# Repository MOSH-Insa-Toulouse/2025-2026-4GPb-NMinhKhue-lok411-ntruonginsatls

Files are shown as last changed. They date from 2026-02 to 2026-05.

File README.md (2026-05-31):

# Projet: Capteur Graphite à Crayon
MOSH projet crée par les étudiant.es en 4ème année de Génie Physique: 
**NGUYEN Minh Khue, VO Phuc Loc, TRUONG Nguyen Gia Khanh**

# Tableau de matière
- [Introduction](#introduction)
  - [Objectifs](#1-objectifs)
  - [Conception](#2-conception)
  - [Matériels nécessaires](#3-matériels-nécessaires)
  - [Livrables](#4-livrables)
- [Réalisation du projet](#réalisation-du-projet)
  - [Schémas](#1-schémas)
    - [Wiring diagram et Simulation LTspice](#11-wiring-diagram-et-simulation-ltspice)
    - [Connection diagram et KiCad](#12-connection-diagram-et-kicad)
  - [Software](#2-software)
    - [Code Arduino](#21-code-arduino)
    - [Application Android sur MIT App Inventor](#22-application-android-sur-mit-app-inventor)
  - [Banc de test](#3-banc-de-test)
    - [Principe](#31-principe)
    - [Résultats](#32-résultats)
- [Conclusion](#conclusion)
- [Contacts](#contacts)
## Introduction

### 1. Objectifs
Le projet est dans le cadre de l’UF « Du capteur au banc de test en open source hardware » en 4ᵉ année de Génie Physique à l’INSA Toulouse. Il est inspiré du rapport scientifique "Pencil Drawn Strain Gauges and Chemiresistors on Paper", publié en 2014 par Cheng-Wei Lin*, Zhibo Zhao*, Jaemyung Kim & Jiaxing Huang dans lequel les auteurs ont proposé un nouveau type de jauge de contrainte basé sur graphite. Le principe repose sur le fait que la résistance électrique du graphite varie lorsque le papier est déformé. En effet, la déformation modifie la distance entre les grains de graphite, ce qui entraîne une variation de la conductance du capteur. En mesurant cette variation de résistance, il est possible d’estimer la contrainte appliquée.

Le premier objectif est donc de concevoir un système qui nous permet de faire un banc de test en mesurant les capteurs simples à graphite pour les comparer avec les capteurs commerciales. De plus, le système doit être contrôlable. Le deuximème objectif est d'évaluer l'industriabilité de ce nouveau type de capteur à partir des mesures.

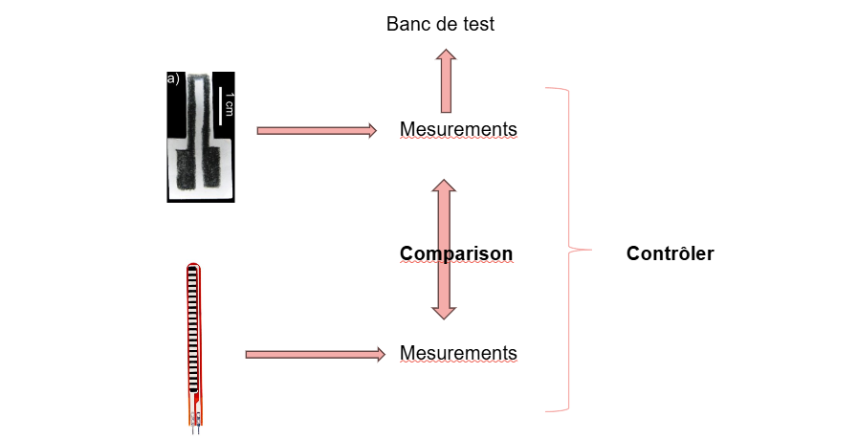
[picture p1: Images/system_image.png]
Système
 

### 2. Conception
Pour regrouper plusieurs fonctions, cela vaut mieux que nous réalisons un shield Arduino. Nous pouvons contrôler les mesures soit manuellement avec un encoder rotatif via un écran OLED, soit à distance via un module Bluetooth et une application Android. Toutes ces idées sont synthétisé dans la figure ci-dessous.

Les détails sont décrits dans la partie de la réalisation.

(apres) nous avons manuellement soudé l'ensemble des modules arduino et composants électroniques (résistances, capacités, amplificateur opérationnel) au PCB imprimé.

(apres) Le Shield réalisé intègre un amplificateur de signal LTC1050 pour amplifier les faibles signaux des capteurs avec précision, un encodeur rotatif permettant de naviguer dans le menu et de modifier les valeurs de résistance via un potentiomètre, un écran OLED pour afficher clairement les menus et les informations, ainsi qu’un module Bluetooth assurant la communication sans fil avec un téléphone portable pour le contrôle et la supervision à distance du système.

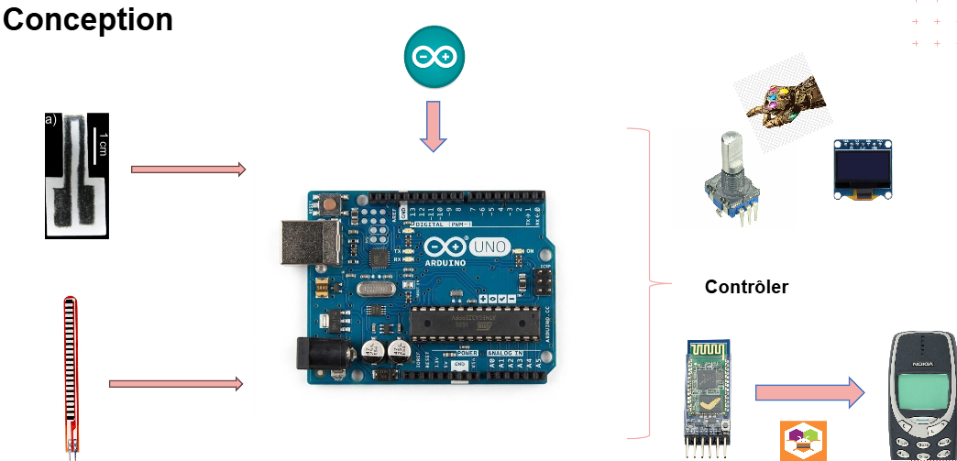
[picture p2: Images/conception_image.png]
Shield


### 3. Matériels nécessaires 
Avec la conception, nous avons décidé que ces composants listés ci-dessous sont suffisants, tout est disponible dans la salle d'instrumentation :
- 1 Carte Arduino UNO
- 1 Module Bluetooth (HC-05)
- 1 Encoder rotatif (Keyes KY-040)
- 1 Écran OLED
- 1 Capteur en graphite fait à l'aide de la couche d'un crayon de papier
- 1 Capteur de flexion commercial (LLC 1070)
- 1 Potentiomètre numérique (MCP41100)
- 1 Amplificateur de transimpédance (LTC1050)
- 2 Supports IC 
- 1 Résistance 1kΩ, 2 résistances 10kΩ, 2 résistances 100kΩ
- 3 condensateurs 100nF, 1 condensateur 1µF

### 4. Livrables
Plusieurs livrables sont contenus dans notre repositoire :
- **Un shield PCB connecté à une carte Arduino UNO** avec differents composants.
- Fiches techniques des composants (HC-05, Keyes KY-040, SSD 1306, LLC 1070, LTC1050, MCP41100)
- **Un code Arduino** qui gère les différents composants cités précédemments (mesures de résistance d'une jauge de contrainte faite en graphite, la communication avec un module Bluetooth, l'affichage sur l'écran OLED d'actions possibles et la gestion du potentiomètre digital permettant la calibration de notre capteur).
- **Une application Android** (grâce aux Tutoriels MIT App Inventor) permet de connecter le PCB et le code Arduino.
- La datasheet du capteur de contrainte en graphite.
- Les fichiers de simulation LTSpice et KiCad.

## Réalisation du projet

### 1. Schémas
La réalisation doit tout d'abord commencer par des schémas électriques tels que le Wiring diagram et le Connection diagram.

#### 1.1. Wiring diagram et Simulation LTspice
Ce diagramme a pour but de savoir comment on peut connecter le capteur à l'Arduino afin que les signaux des mesures soient captées par l'Arduino.

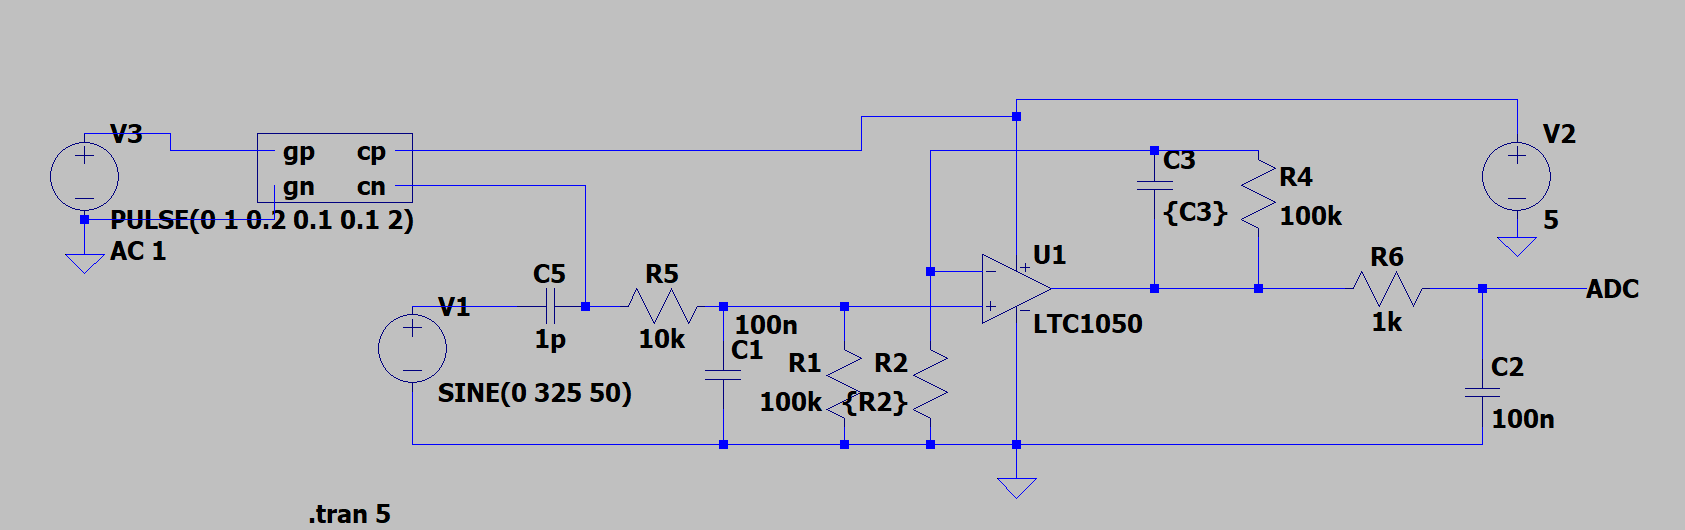
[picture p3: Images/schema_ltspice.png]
Schéma du montage sur LtSpice


Nous souhaitons mesurer la résistance de notre capteur en graphite. Lorsque la résistance interne de notre capteur de graphite est de l'ordre du GΩ. Le courant généré lorsque nous appliquons une tension de 5V est très faible. Pour pouvoir utiliser ce signal, nous le faisons passer par un amplificateur transimpédance (ici nous choisissons LTC 1050) car il possède une capacité à accepter en entrée un courant très faible et un offset de tension bas. Ce montage est constitué d'un amplificateur opérationnel (AO) pour fournir un signal suffisamment large au convertisseur analogique-numérique (ADC) de l'Arduino UNO.

En plus de l'AOP, nous ajoutons 3 filtres:
- À l'entrée, un filtre passe bas passif composé de R1 et C1 de fréquence de coupure de 16Hz pour filtrer les bruits en courant sur le signal d'entrée.
- Une filtre passe bas actif composé de R3 et C4 de fréquence de coupure de 1.6Hz permettane de filtre la composante de bruit à 50Hz provenant du couplage avec le réseau éléctrique.
- En sortie, un dernier filtre composé de R6 et C2 de fréquence de 1.6kHz qui permet de retirer le bruit créé pendant le traitement i.e. bruits des alimentations, de l'horloge, etc.

La résistance R5 est placé en amont de l'AO pour le protéger contre des décharges électrostatiques. Pour notre simulation, nous avons placé la capacité C3 de sorte à ce qu'elle filtre le bruit de l'alimentation. Ainsi, la résistance R2 sera remplacé par une résistance variable (un potentiomètre digital) qui va nous permettre de régler le gain de notre AO en fonction de notre besoin.

Une fois dessiné le Wiring diagram, nous avons vérifié ses comportements et les valeurs de ses composants électriques (résistances, condensateurs,e tc.) grâce aux simulations du logiciel LTspice. (voir l'onglet caché ci-dessous)
<details>
<summary><strong>Simulation LTspice</strong></summary>

- **Fonctionnalité de condition nominale**

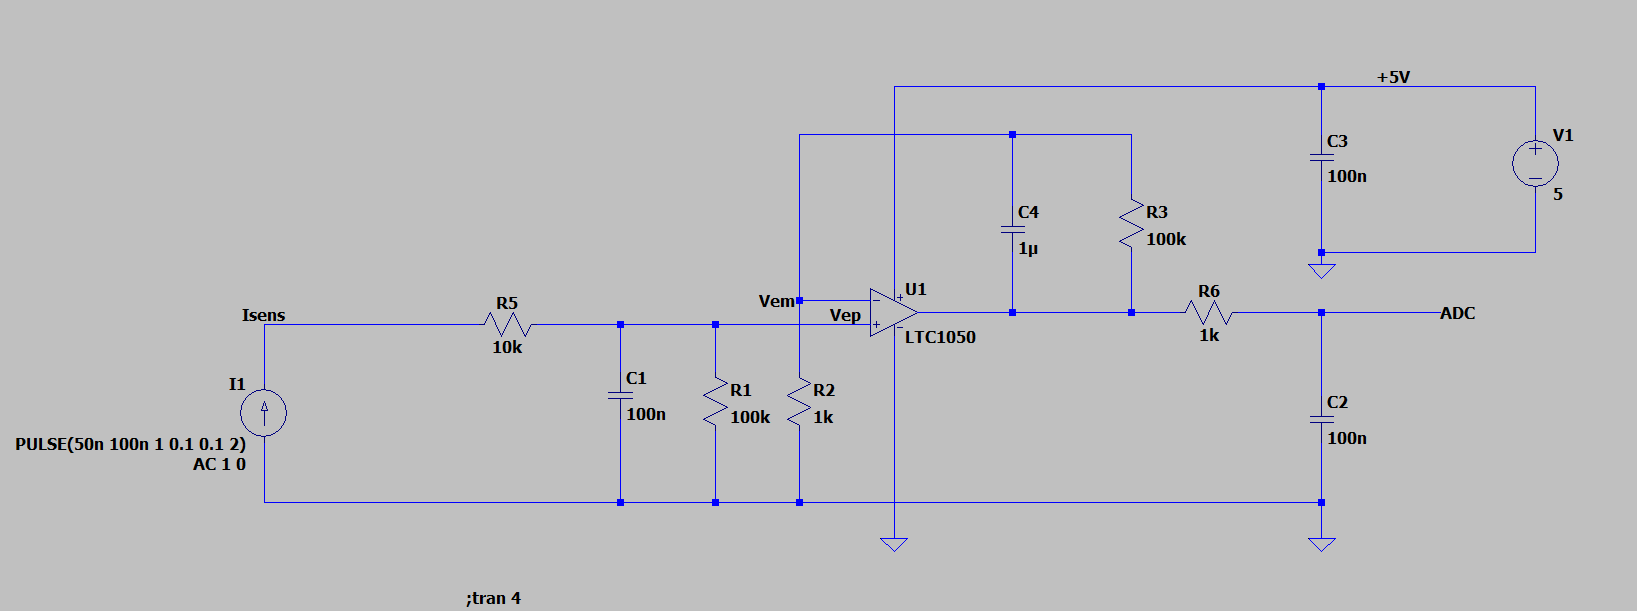
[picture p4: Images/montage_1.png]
montage


Le courant d’entrée Isens varie entre 50 nA et 100 nA, ce qui entraîne une variation de la tension Vep appliquée à l’entrée non-inverseur V+ du LTC1050, entre 5 mV et 10 mV.

Le gain de l’amplificateur du LTC1050 est défini par : G = 1 + R3/R2 = 101. Par conséquent, la valeur de la tension de sortie du LTC1050 varie entre 0.5 V et 1 V.

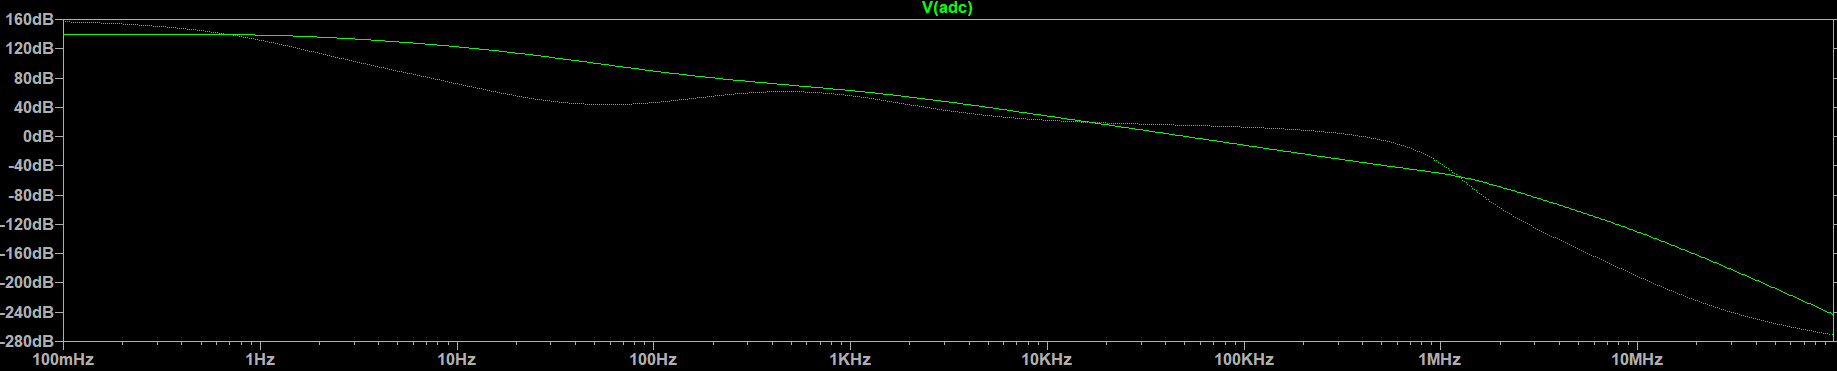
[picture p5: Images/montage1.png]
resultat


Au départ, le signal exprimé en décibels est de 140 dB, ce qui correspond à : 20 log(VADC / Isens).

Le microcontrôleur utilisé est un Arduino UNO, basé sur un microcontrôleur AVR avec une fréquence d’échantillonnage maximale fech = 200 kHz.
Comme la conversion analogique-numérique se fait sur 13 bits, la fréquence d’échantillonnage réelle est limitée à 15.4 kHz.

D'après le théorème de Nyquist, la fréquence maximale du signal que l'on peut correctement numériser doit donc être inférieure à la moitié de cette valeur :
fsignal < fech/2 = 7.7 kHz.

- **Modélisation du capteur**
  - Le bruit à 50 Hz, généré notamment par l'écran TFT (bruit de type secteur), est clairement observé dans le spectre du signal. Pour l’atténuer, on agit sur le condensateur C4 du filtre passe-bas.

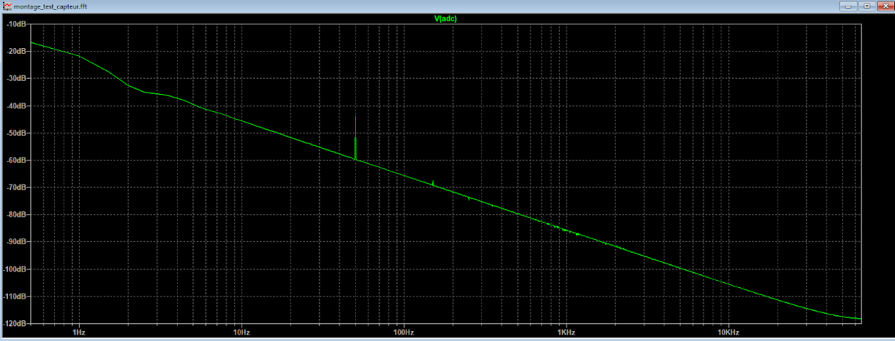
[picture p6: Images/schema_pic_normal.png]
test montage normal


  - Lorsque la valeur de C4 est augmentée à 10 µF, le pic de bruit à 50 Hz est fortement réduit, ce qui indique une amélioration de l’atténuation dans les basses fréquences.

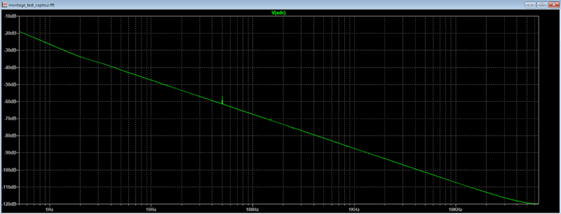
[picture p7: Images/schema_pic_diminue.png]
test montage diminue


  - En revanche, si on diminue la valeur de C4, le bruit augmente, montrant que la fréquence de coupure du filtre remonte et que le bruit secteur passe plus facilement.

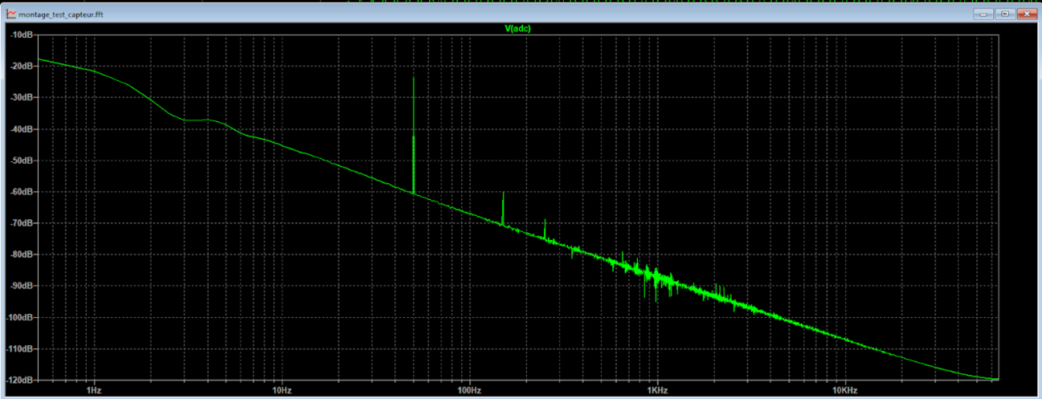
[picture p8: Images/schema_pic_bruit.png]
test montage augment


- **Résultat**
Une photo démontrant que notre circuit permet une amplification efficace du signal délivré par le capteur :
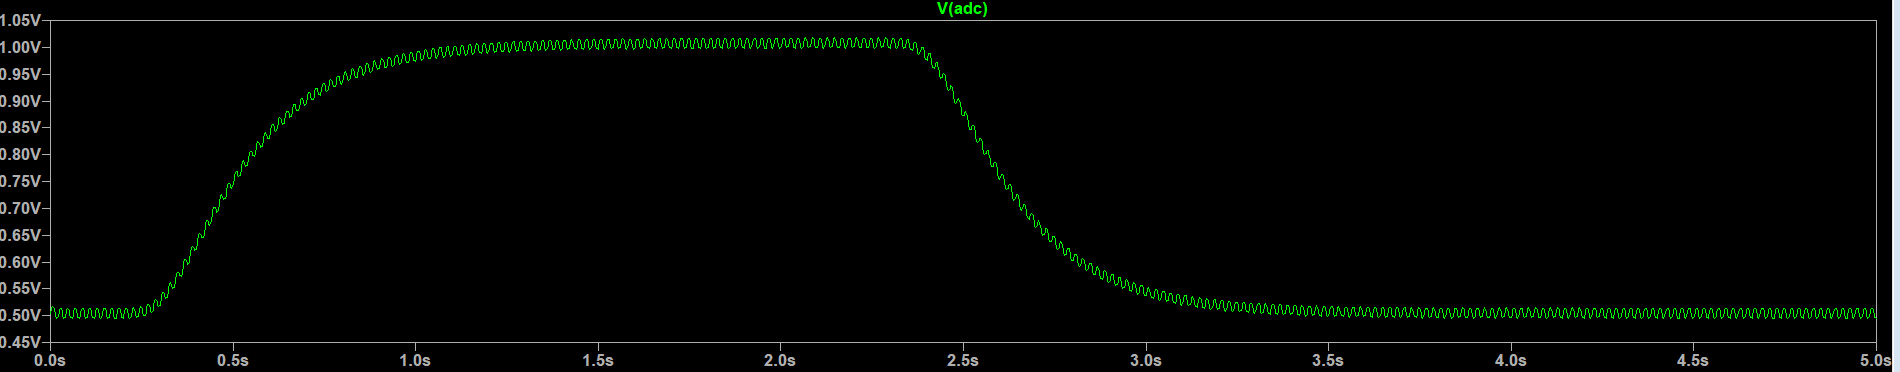
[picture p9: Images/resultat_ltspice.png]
resultat final


</details>

#### 1.2. Connection diagram et KiCad
Après le Wiring diagram, nous avons dessiné le diagramme des connexions afin de déterminer les connexions entre les broches des différents composants. Nous l'avons réalisé avec le logiciel KiCad car ce logiciel nous aiderait les étapes après.

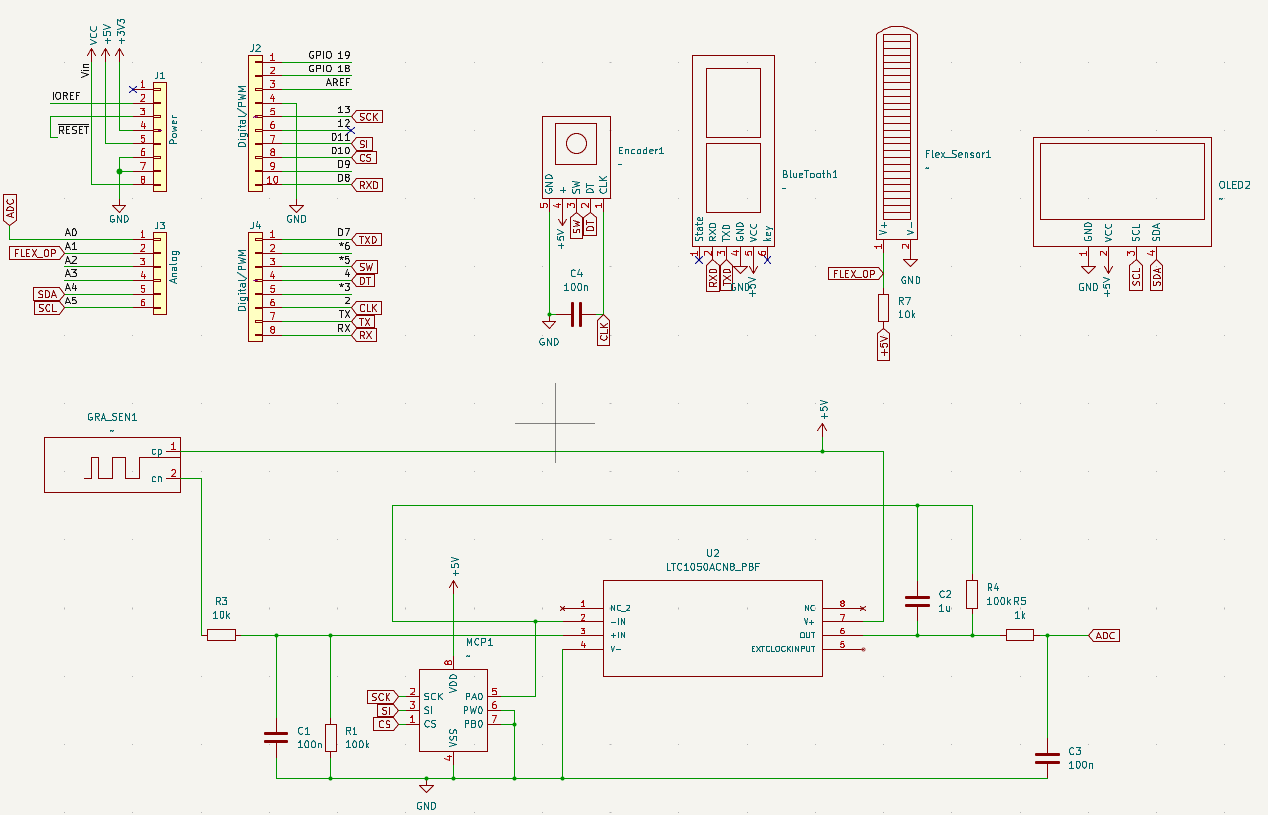
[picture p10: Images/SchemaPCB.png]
Schéma électronique réalisé sur KiCad


Nous vous expliquons les réalisations sur KiCad :

- Réalisation des symboles et des empreints :
Pour commencer notre PCB (Printed Circuit Board), il est nécessaire de créer les symboles et les empreintes des composants qui ne sont pas disponibles dans la bibliothèque de KiCad. Nous avons réalisé les symboles du module Bluetooth, de l'encodeur rotatif, de l'écran OLED, du capteur de flexion et du capteur en graphite, afin de les ajouter au schéma de connexion. Ensuite, ces symboles ont été associés à une empreinte trouvée sur des sites de libre téléchargement.

- Réalisation du schéma électronique (Connection diagram) :
Ensuite, le schéma électronique est à construire. Dans cette partie, les différentes connexions entre composants sont définies et les pins de la carte Arduino sont attribués à chacun des composants.

- Réalisation du routage :
L'objectif ici était d'allouer un branchement sur les entrées d'une carte Arduino UNO à chaque module. Nous avons aussi pour but de faire le moins possible de via (pont traversant permettant de chavaucher un routage). Le circuit imprimé a été dessiné avec une attention particulière portée à la disposition des pistes pour minimiser les couplages parasites et faciliter le routage manuel.
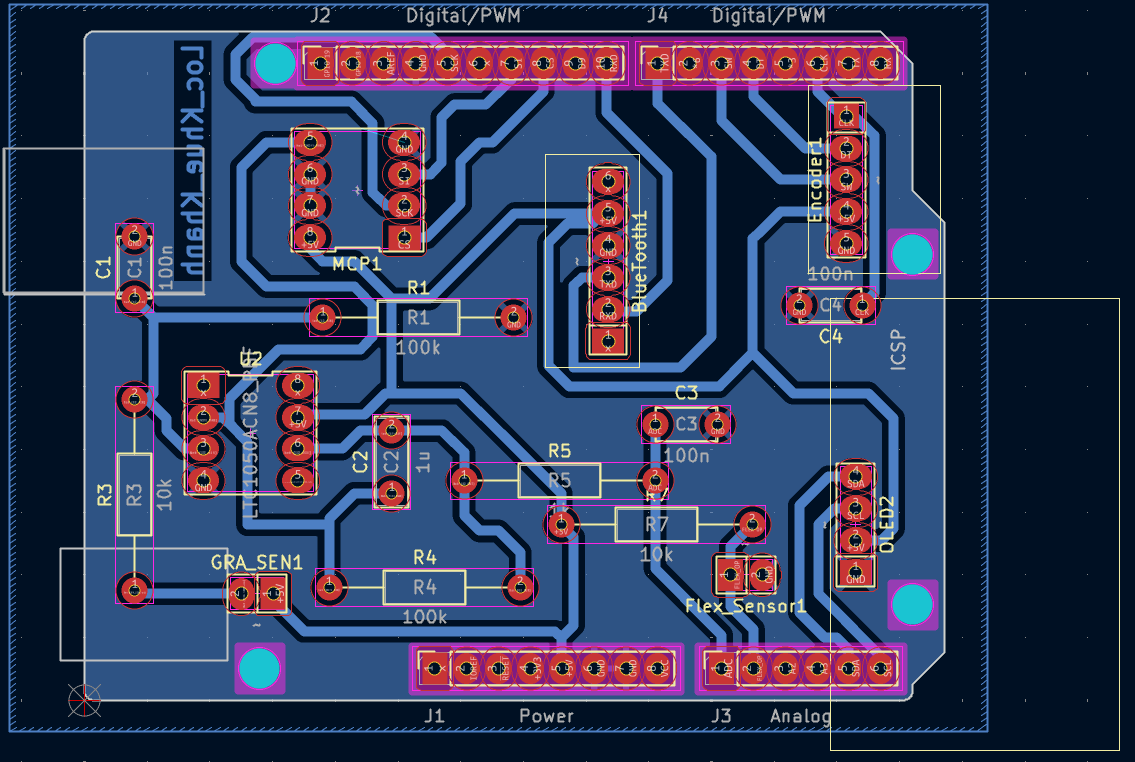
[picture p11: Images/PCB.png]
Schéma du PCB


L'ensemble des fichiers KiCad est disponible dans le dossier [Shield TP Arduino par KiCad](Shield%20TP%20Arduino%20par%20KiCad).

#### 1.3. Résultat
L'image de 3D du PCB :

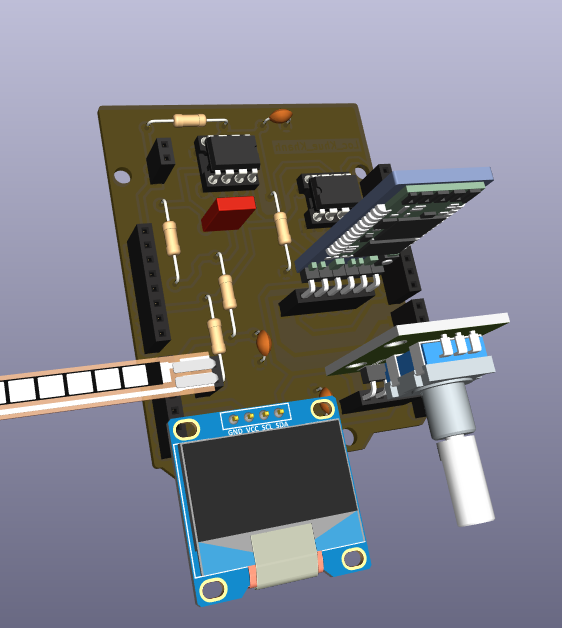
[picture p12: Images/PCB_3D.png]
Schéma du PCB 3D


Le PCB physique :

Shield assemblage

### 2. Software

Nous avons passé à la partie de software une fois celle de hardware est finie.

#### 2.1. Code Arduino
Le code Arduino permet de lire les valeurs du capteur en graphite, de gérer l'affichage d'un Menu sur l'écran OLED, la communication par Bluetooth avec l'application Android et le contrôle via l'encodeur rotatif.

Le code Arduino est disponible dans le dossier [Programme Arduino](Programme%20Arduino).

#### 2.2. Application Android sur MIT App Inventor
Cette application permet de communiquer avec le système de mesure via Bluetooth et d’afficher les valeurs de résistance des capteurs.

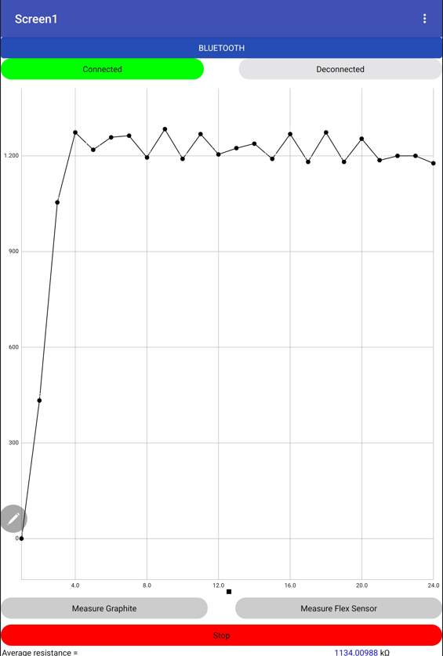
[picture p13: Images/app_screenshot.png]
Application MIT


Lorsque la connexion Bluetooth est réussie, le bouton Connected devient vert, ce qui indique que la liaison est établie.

L’application propose deux modes de mesure :
- Measure Graphite : mesure la résistance du capteur graphite ;
- Measure Flex Sensor : mesure la résistance du capteur flex en fonction du temps.
Les valeurs mesurées sont affichées sur le graphique au centre de l’écran. À la fin de la mesure, les données sont regroupées, la valeur moyenne de la résistance est calculée, puis affichée en bas de l’interface.

### 3. Banc de test
Pour valider le fonctionnement du système, nous faisons évaluer les performances de notre capteur à travers un banc de test.

#### 3.1. Principe

Un modèle 3D composé de fentes circulaires de différents rayons est utilisé pour le banc de test. En insérant le capteur dans ces fentes, une déformation est induite en fonction de son orientation (traction ou compression). La déformation est inversement proportionnelle au rayon des fentes circulaires, selon la relation suivante : 
ε = e / 2R

Où :
ε : déformation
e : allongement imposé
R : rayon de la fente (0,2 mm)

Ce système permet de contrôler précisément la déformation du capteur en choisissant simplement un rayon de fente spécifique.

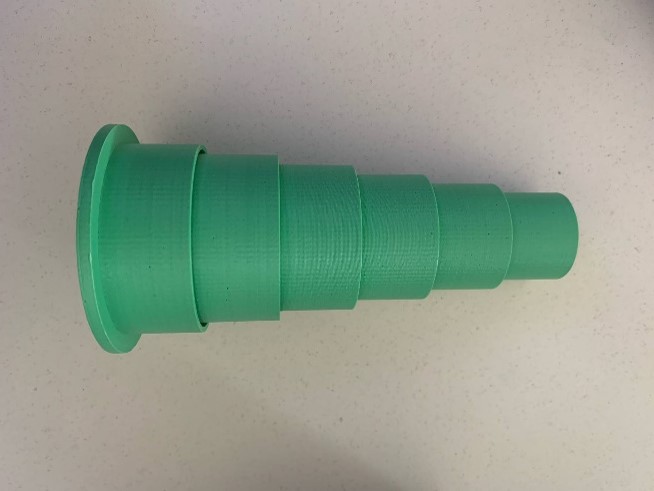
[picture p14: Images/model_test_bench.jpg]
model test


<details>
<summary><strong>Explication de la physique derrière la capteur à graphite</strong></summary>
Lorsque le capteur est déformé, sa résistance varie naturellement. Ce phénomène s’explique principalement par les changements de distance entre les atomes de carbone qui le composent.

En traction, les atomes s’éloignent les uns des autres. Les chemins conducteurs entre les deux extrémités du capteur deviennent alors moins nombreux et moins continus. Les électrons circulent donc plus difficilement, ce qui entraîne une augmentation de la résistance.

À l’inverse, en compression, les atomes se rapprochent. Les contacts entre particules sont facilités, ce qui crée davantage de chemins conducteurs. Les électrons passent alors plus facilement et la résistance diminue.

On observe également que la résistance diminue lorsque la dureté du crayon augmente. Cela s’explique simplement par une plus faible proportion de carbone dans le matériau.

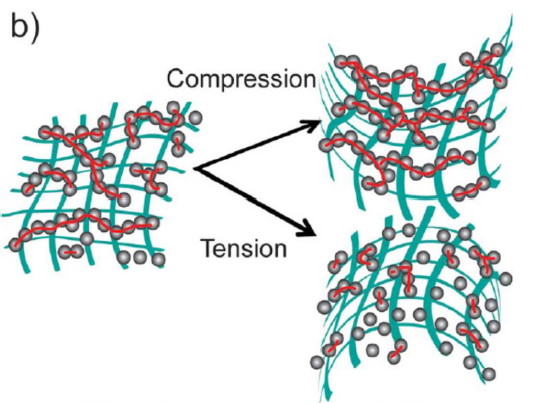
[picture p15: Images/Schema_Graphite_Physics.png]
Graphite Physiques


</details>
  
#### 3.2. Résultats

Par la suite, nous avons caractérisé notre capteur en graphite afin de reproduire les résultats présentés dans l’étude mentionnée ci-dessus. La tension aux bornes du capteur est mesurée puis convertie en valeur de résistance. Cette résistance est ensuite tracée en fonction de la déformation appliquée.

Les graphiques ci-dessus montrent la variation relative de la résistance du capteur en fonction de la déformation dans deux modes : traction et compression. Des droites de régression linéaire passant par l’origine ont été ajustées, montrant que la variation relative de résistance (ΔR/R₀) évolue linéairement avec la déformation.

Variation des résistances en fonction de déformation en mode traction
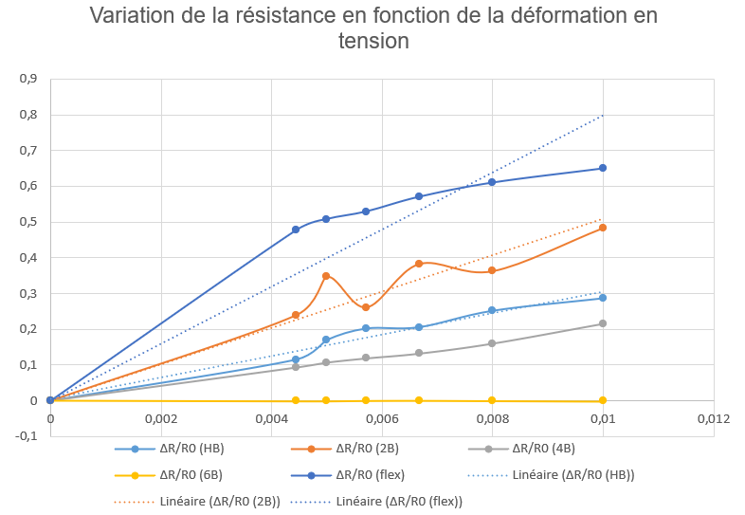
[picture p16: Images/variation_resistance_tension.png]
Variation de resistance de traction


Variation des résistances en fonction de déformation en mode compression
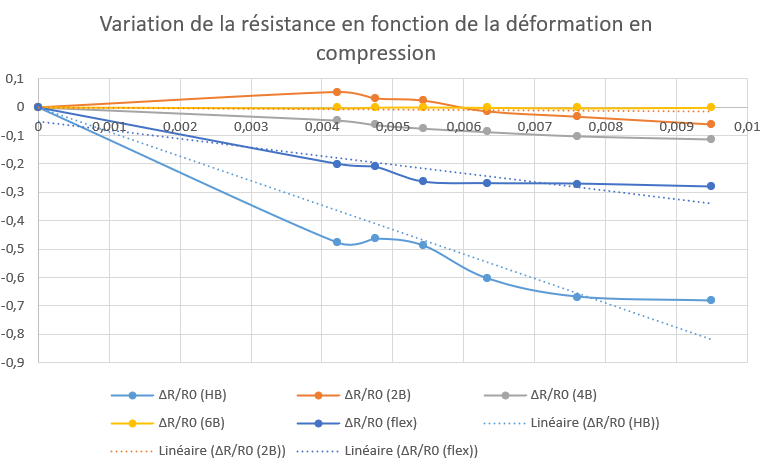
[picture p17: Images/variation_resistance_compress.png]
Variation de resistance de compression


**Remarque**
Le capteur à graphite n’est pas très exacte, car les valeurs de résistance changent beaucoup d’une mesure à l’autre, même quand on répète la même manipulation. Cela signifie que les résultats ne sont pas stables et qu’il est difficile de faire confiance aux mesures obtenues. Cette instabilité peut venir de plusieurs facteurs. Par exemple, le papier support peut se plier ou s’abîmer légèrement; le dépôt de graphite peut se fissurer ou se déplacer; le capteur absorbe l'humidité de son environnement. À l’intérieur du capteur, le courant passe grâce au contact entre de petites particules de graphite. Si ces contacts changent après chaque déformation, même un peu, la résistance peut varier fortement.

En comparaison, un capteur industriel comme un flex sensor est conçu pour être plus robuste. Sa structure interne est mieux contrôlée, ce qui permet d’obtenir des mesures plus stables et répétables. Les résultats changent donc beaucoup moins entre plusieurs essais, ce qui le rend plus fiable dans des applications pratiques. Cependant, si on ne concernait que les applicaitons qui ne requièrent pas des mesures exactes mais que une déformation, ce type de capteur à graphite est ainsi un bon outil. 

## Conclusion

Dans ce travail, nous avons fabriqué un capteur de déformation en graphite sur les papiers et avons étudié comment sa résistance change lors des déformations.

Les résultats montrent que la résistance varie bien avec la déformation, ce qui confirme le principe du capteur. Cependant, les valeurs mesurées ne sont pas stables et changent d’une mesure à l’autre. Cela est probablement dû à la structure du graphite, qui n’est pas uniforme, ainsi qu’à la qualité des contacts et au support en papier qui peut se déformer.

Ainsi, même si ce capteur est simple et peu coûteux, il reste peu exacte dans sa forme actuelle. Il serait donc difficile de l’utiliser en industrie pour les applications requises l'exactitude. Par contre, pour les applications de détection de déformation, il est bien adapté.

## Contacts
Pour toutes les informations complémentaires: 
### Étudiant.es réalisé.es :
- NGUYEN Minh Khue : mngu@insa-toulouse.fr
- VO Phuc Loc : pvo@insa-toulouse.fr
- TRUONG Nguyen Gia Khanh : ntruong@insa-toulouse.fr

### Enseignant.es :
- Jérémie Grisolia : jeremie.grisolia@insa-toulouse.fr
- Arnauld Biganzoli : arnauld.biganzoli@insa-toulouse.fr
- Cathy Crouzet : crouzet@insa-toulouse.fr
- Benjamin Mestre : benjamin.mestre@scalian.com

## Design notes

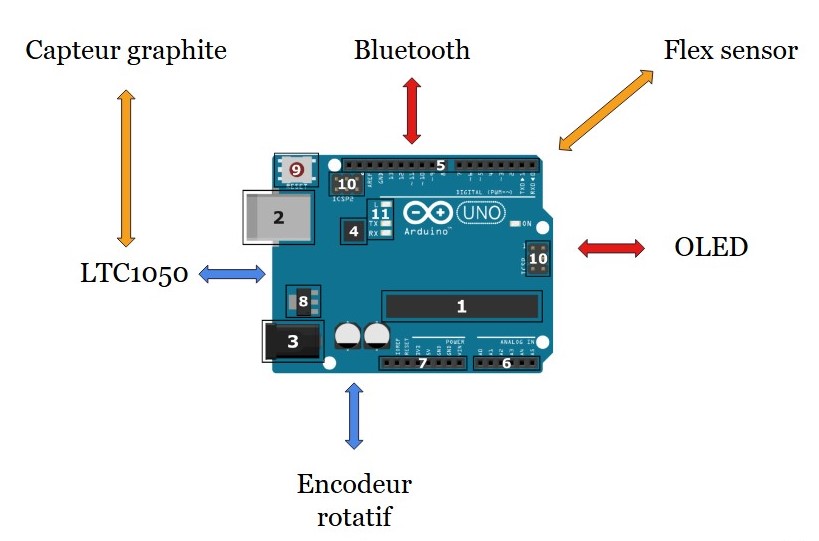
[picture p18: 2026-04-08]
Images/Shield.jpg

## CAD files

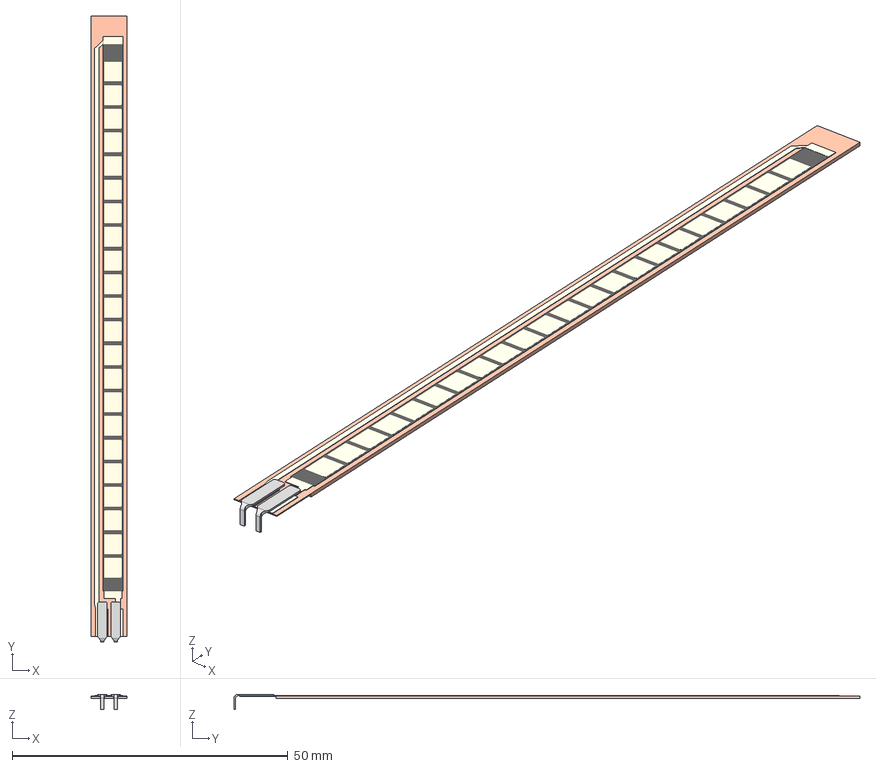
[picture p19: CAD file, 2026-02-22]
Shield TP Arduino par KiCad/3D model/Flex Sensor/FS-L-0095-103-ST - Assembly.stp
6.45 x 113.5 x 2.77 mm
FS-L-0095-103-ST - Base
FS-L-0095-103-ST - Top

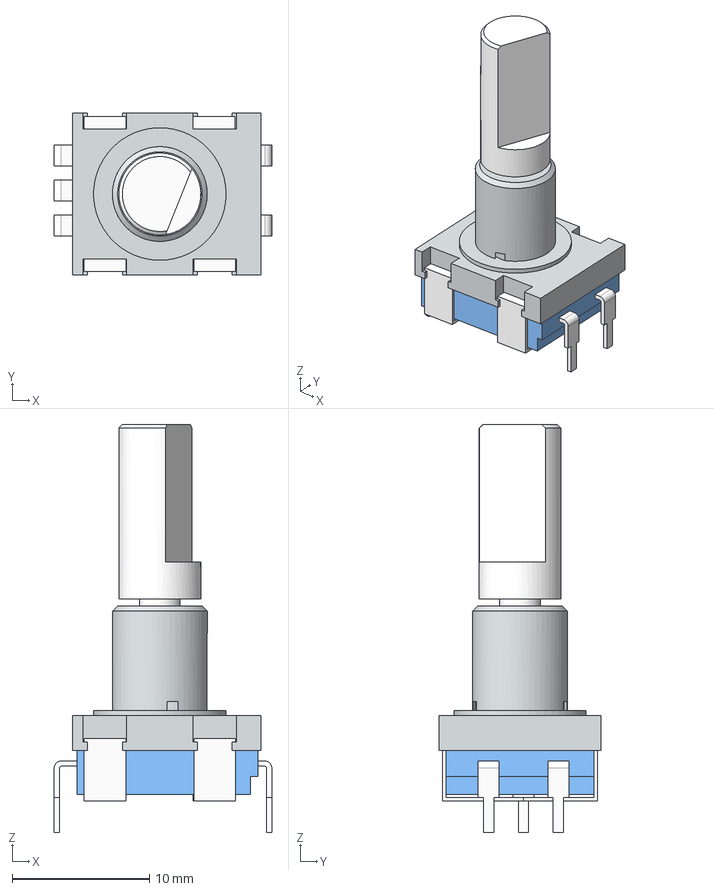
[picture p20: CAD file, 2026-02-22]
Shield TP Arduino par KiCad/3D model/Encodeur rotatoire/Rotary Encoder without pcb Assembly.stp
15.8 x 11.8 x 29.7 mm
mtg flange
body_encoder
pins_encoder body_2 x 5
shaft_encoder

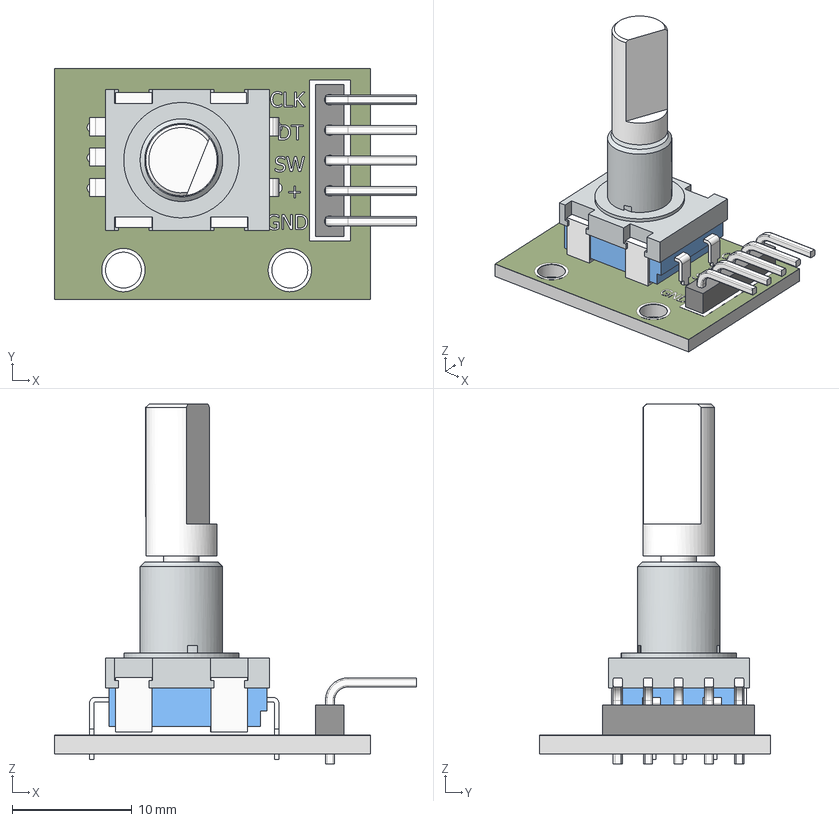
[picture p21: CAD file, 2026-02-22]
Shield TP Arduino par KiCad/3D model/Encodeur rotatoire/rotary encoder_chesr_2013.stp
30.3 x 19.3 x 30.1 mm

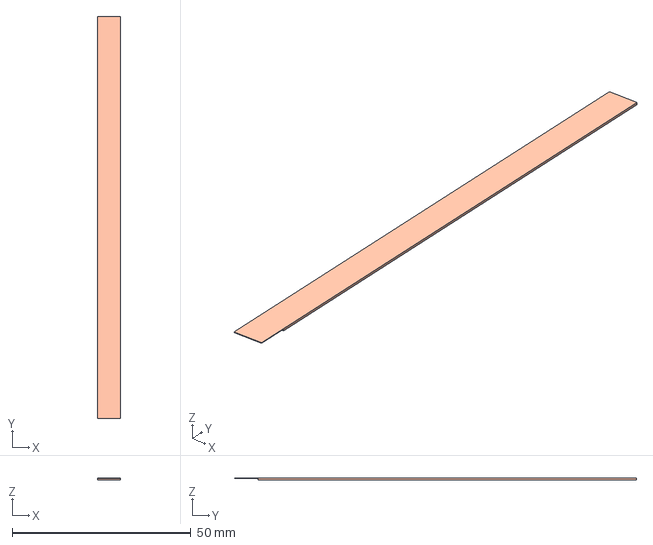
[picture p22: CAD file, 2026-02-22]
Shield TP Arduino par KiCad/3D model/Flex Sensor/SolidEdge/FS-L-0095-103-ST - Base.stp
6.45 x 112.4 x 0.483 mm

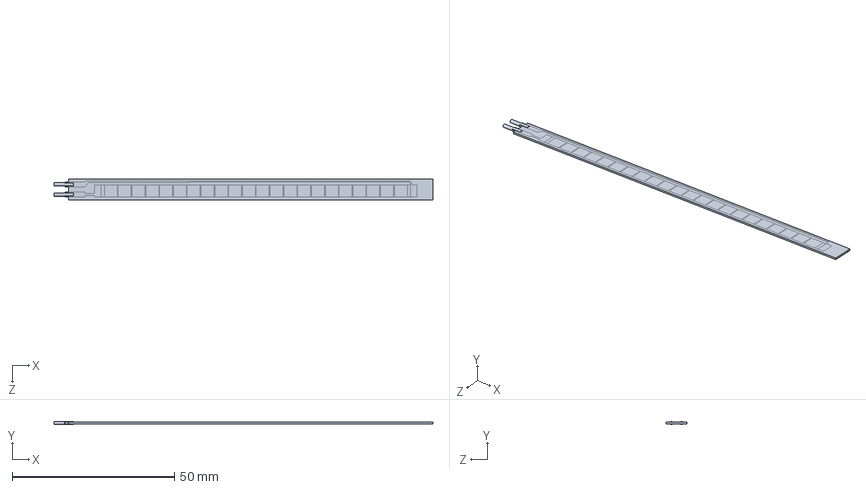
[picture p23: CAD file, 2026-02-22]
Shield TP Arduino par KiCad/3D model/FLEX_SENSOR 115MM/FLEX_SENSOR 115MM.SLDPRT
116.7 x 1.00 x 6.35 mm

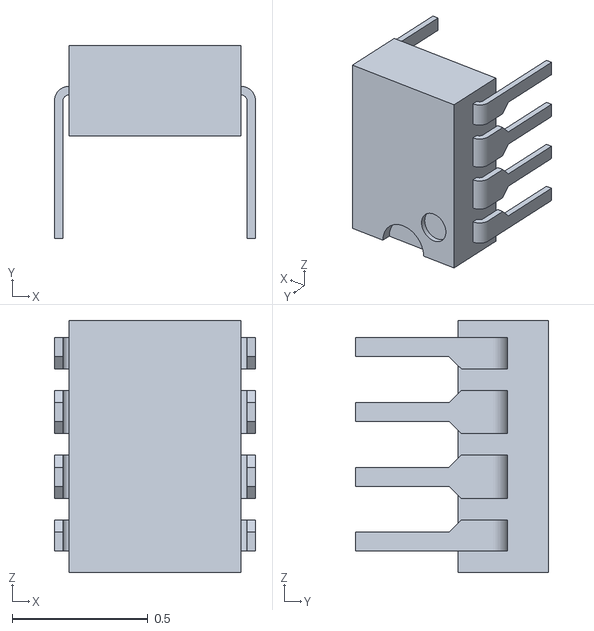
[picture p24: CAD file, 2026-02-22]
Shield TP Arduino par KiCad/3D model/MCP/OP-AMPSTP_IGS.stl
0.741 x 0.712 x 0.928

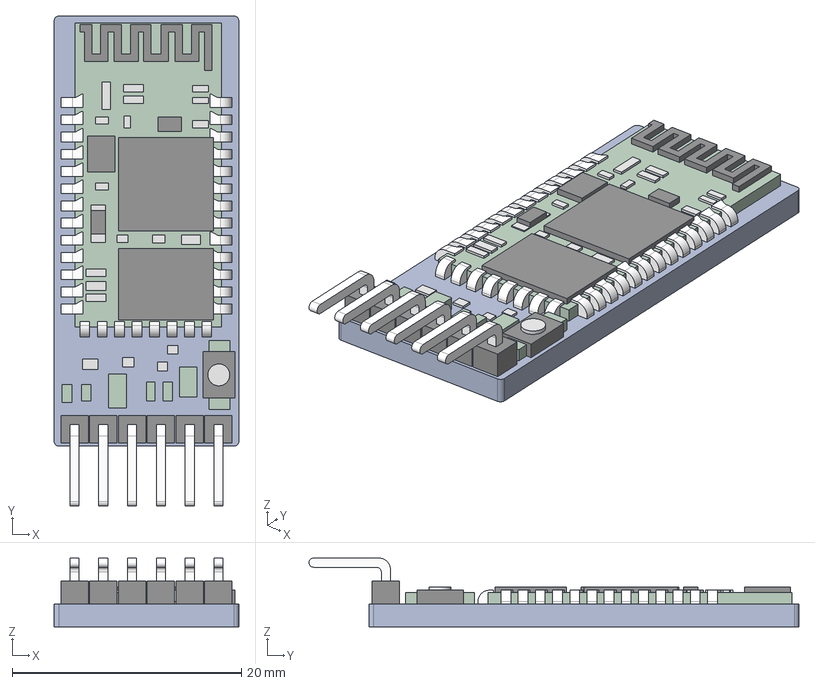
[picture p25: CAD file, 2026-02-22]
Shield TP Arduino par KiCad/3D model/module bluetooth/HC_05 Blue Tooth Module.stp
16.1 x 42.7 x 6.00 mm

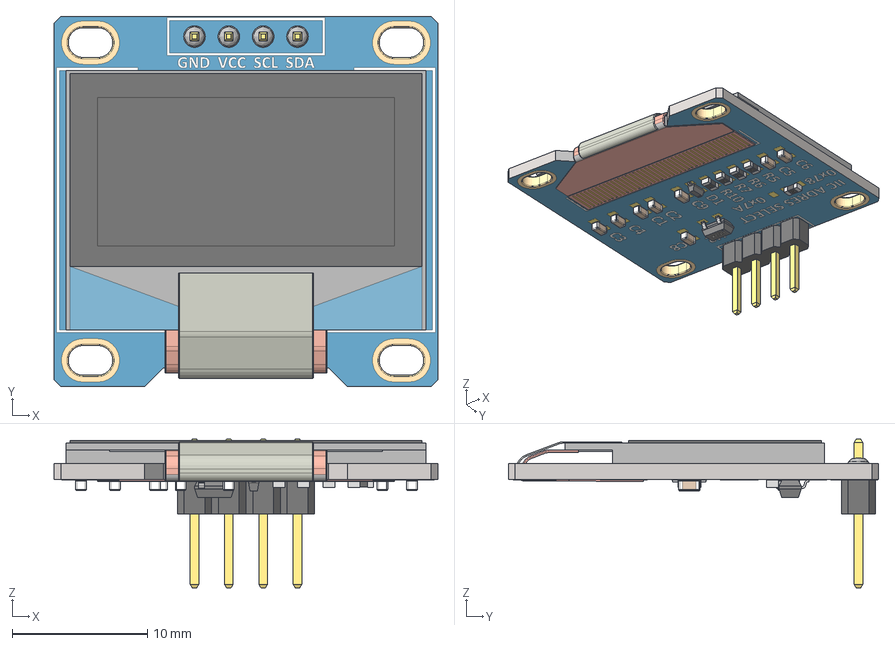
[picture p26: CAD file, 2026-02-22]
Shield TP Arduino par KiCad/3D model/OLED/Pantalla OLED 0.96'' 128x64.stp
28.4 x 27.4 x 11.0 mm
SOT-23_TOR
RES_CR16_MTK_1 x 4
RES_CR16_MTK
SOD323F_DIO

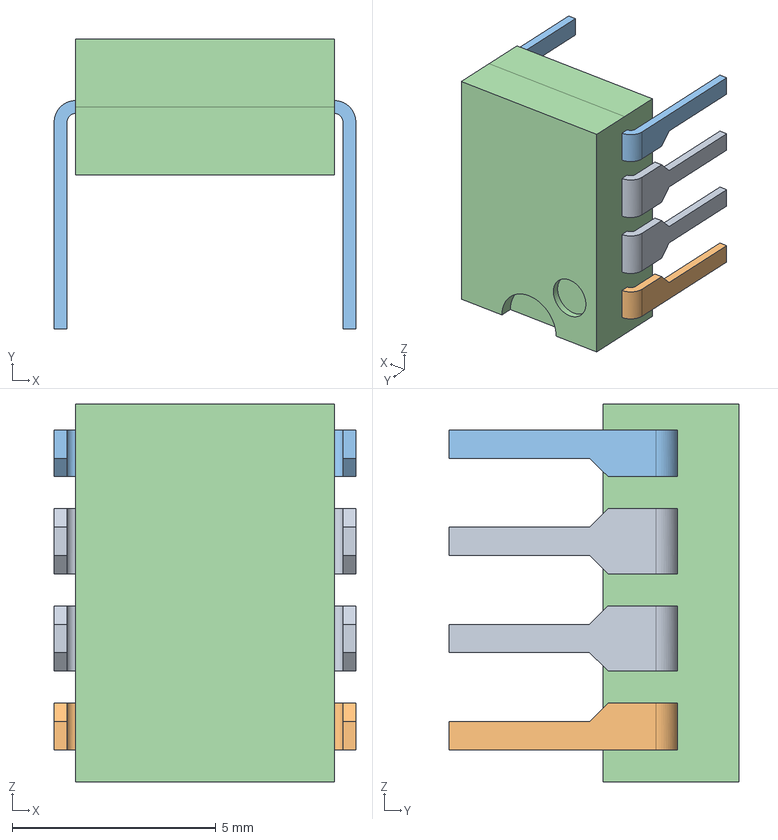
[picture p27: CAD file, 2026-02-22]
Shield TP Arduino par KiCad/3D model/OP-AMP.stp
7.41 x 7.12 x 9.28 mm
Undefined x 9

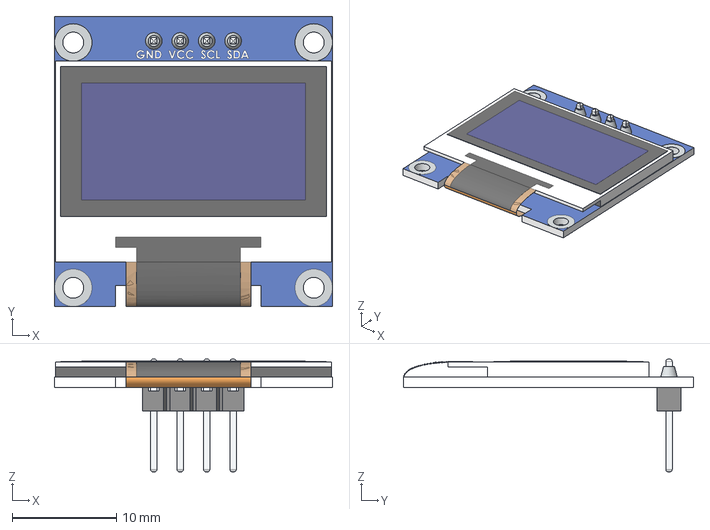
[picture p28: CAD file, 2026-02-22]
Shield TP Arduino par KiCad/OLED-128x64-0.96.step
26.7 x 27.9 x 10.8 mm

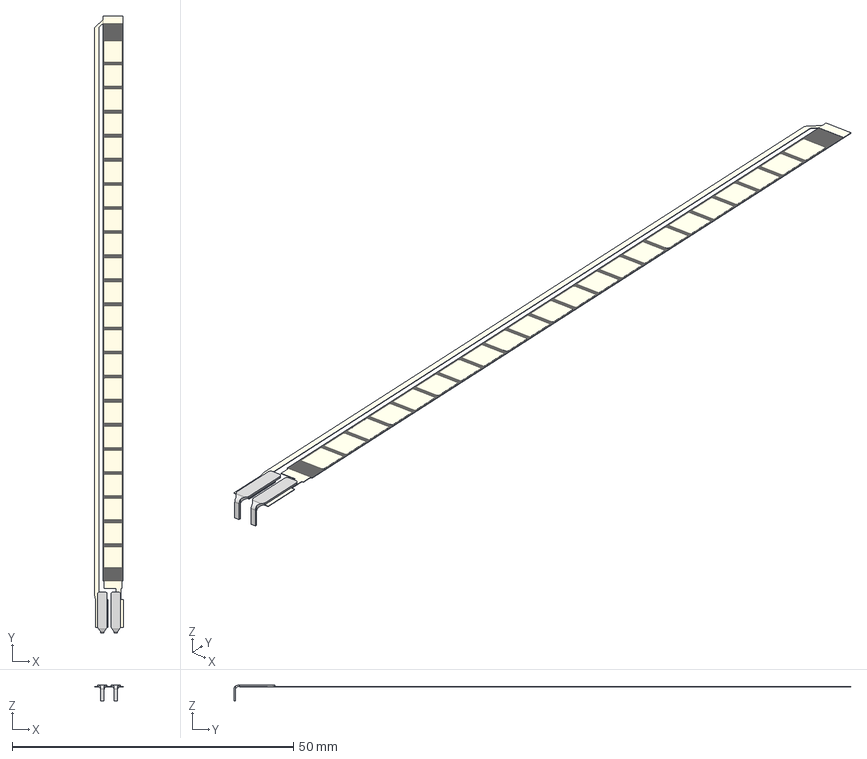
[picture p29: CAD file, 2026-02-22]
Shield TP Arduino par KiCad/3D model/Flex Sensor/SolidEdge/FS-L-0095-103-ST - Top - Right.stp
5.17 x 109.7 x 2.77 mm

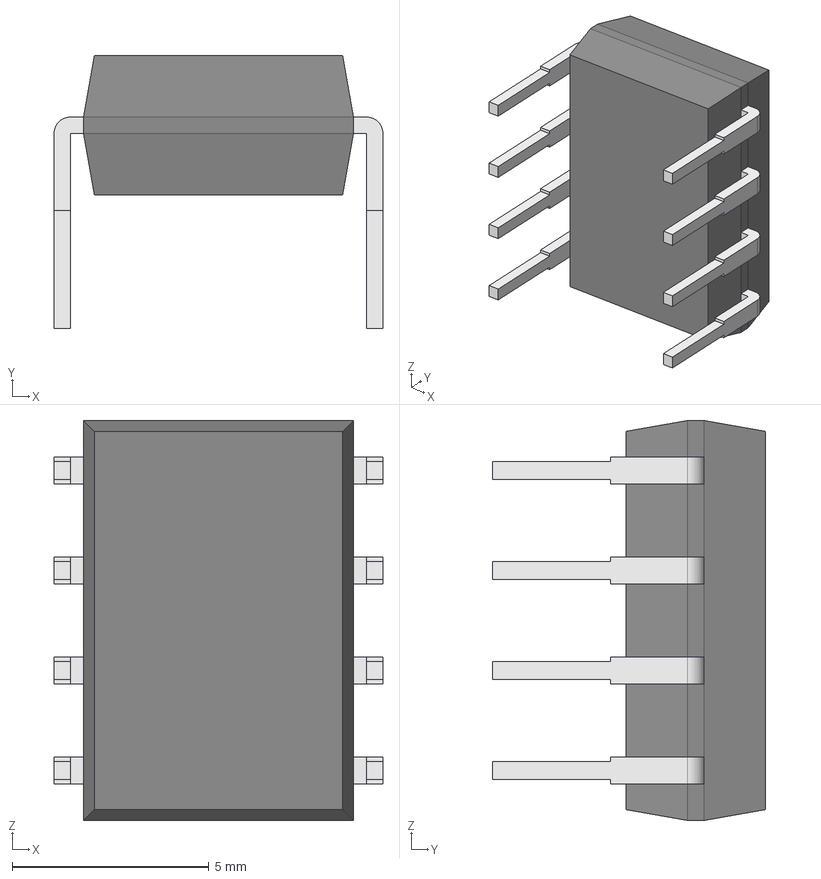
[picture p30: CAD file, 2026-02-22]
Shield TP Arduino par KiCad/LTC1050CN8.step
8.35 x 6.93 x 10.2 mm
Body001 (Mirror #1) x 5

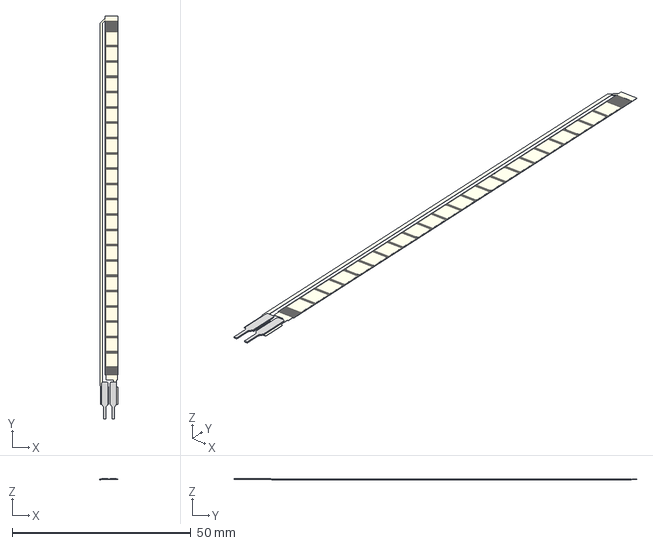
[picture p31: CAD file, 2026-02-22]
Shield TP Arduino par KiCad/3D model/Flex Sensor/SolidEdge/FS-L-0095-103-ST - Top.stp
5.17 x 112.8 x 0.292 mm

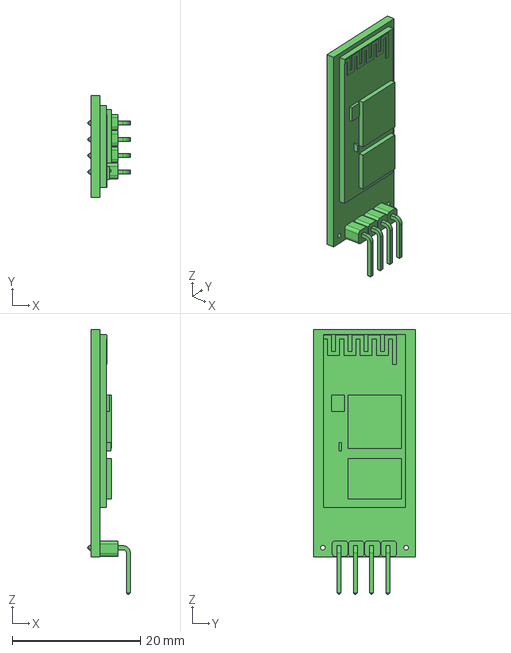
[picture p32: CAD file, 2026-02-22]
Shield TP Arduino par KiCad/HC-05 Bluetooth Module.stp
6.68 x 16.0 x 41.4 mm

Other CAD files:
Shield TP Arduino par KiCad/3D model/module bluetooth/HC_05 Blue Tooth Module.ipt

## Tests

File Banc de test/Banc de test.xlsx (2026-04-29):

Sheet: Data
 | Capteur Graphite |  |  |  |  |  |  |  |  |  | Flex Sensor
 | HB |  | 2B |  | 4B |  | B |  | 6B
Rayon | Avant | Derrière | Avant | Derrière | Avant | Derrière | Avant | Derrière | Avant | Derrière | Avant | Derrière
Pas deformé | 558265792 |  | 454481216 |  | 80236648 |  | 39640232 |  | 80263472 |  | 1109.4
R | 552904448 | 509312384 | 535345024 | 526350048 | 80231944 | 80257136 | 49445408 | 385209.31 | 80238272 | 80231944 | 2216.58 | 1200.15
R -1 | 702961856 | 558713472 | 562016320 | 460420576 | 80271368 | 80255584 | 52809552 | 385102.56 | 80238256 | 80255608 | 2263.14 | 1185
R-2 | 800258304 | 668751488 | 599260864 | 505670688 | 80260320 | 80247704 | 52286920 | 385121.96 | 80252440 | 80261880 | 2294.86 | 1105.69
R-3 | 823527104 | 697712960 | 630649472 | 447743584 | 80250880 | 80258728 | 54853100 | 324136.65 | 80257152 | 80249280 | 2356.23 | 1097.14
R-4 | 995241152 | 731566656 | 661064896 | 442166528 | 80246104 | 80244520 | 72254728 | 385180.28 | 80246136 | 80230368 | 2415.88 | 1094.8
R-5 | 1858133376 | 800019328 | 776613952 | 10016331 | 80242968 | 80257136 | 177406544 | 385092.9 | 80228760 | 80250840 | 2475.27 | 1079.31
0 | 5219604.50 |  | 4664388 |  | 90035744
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

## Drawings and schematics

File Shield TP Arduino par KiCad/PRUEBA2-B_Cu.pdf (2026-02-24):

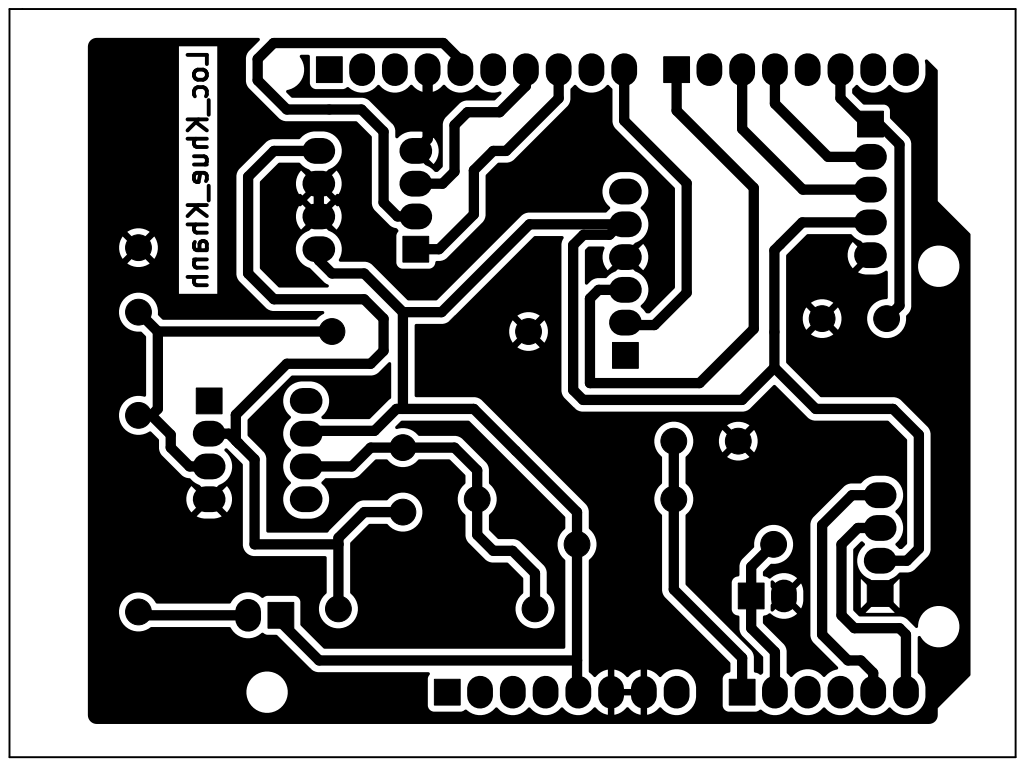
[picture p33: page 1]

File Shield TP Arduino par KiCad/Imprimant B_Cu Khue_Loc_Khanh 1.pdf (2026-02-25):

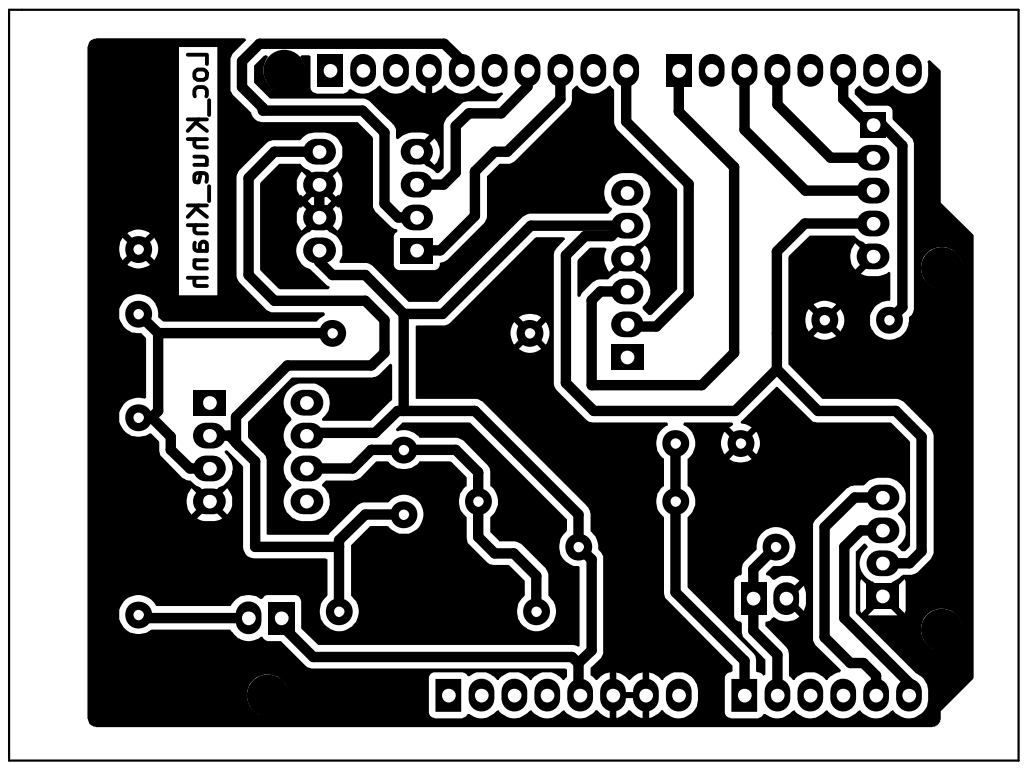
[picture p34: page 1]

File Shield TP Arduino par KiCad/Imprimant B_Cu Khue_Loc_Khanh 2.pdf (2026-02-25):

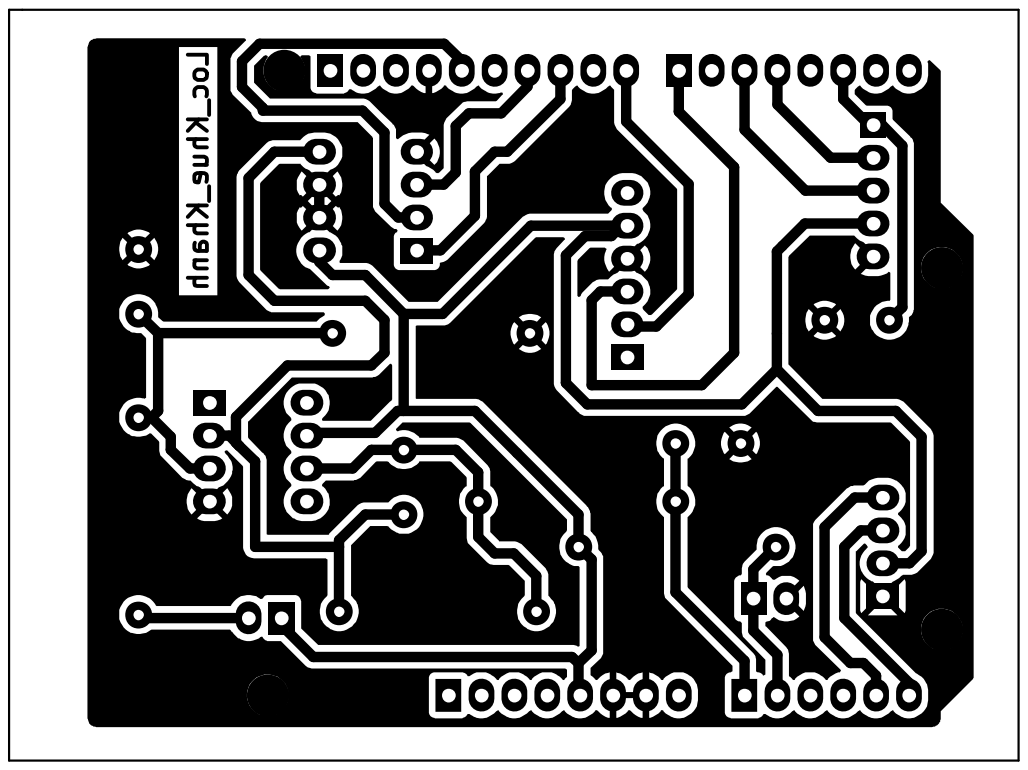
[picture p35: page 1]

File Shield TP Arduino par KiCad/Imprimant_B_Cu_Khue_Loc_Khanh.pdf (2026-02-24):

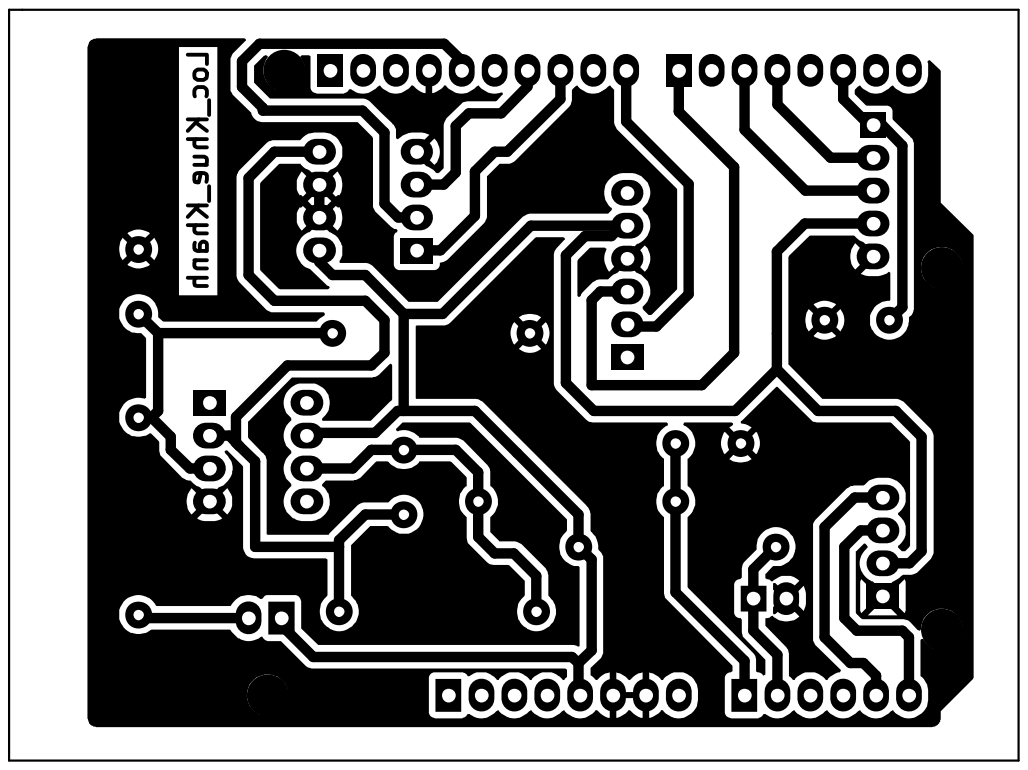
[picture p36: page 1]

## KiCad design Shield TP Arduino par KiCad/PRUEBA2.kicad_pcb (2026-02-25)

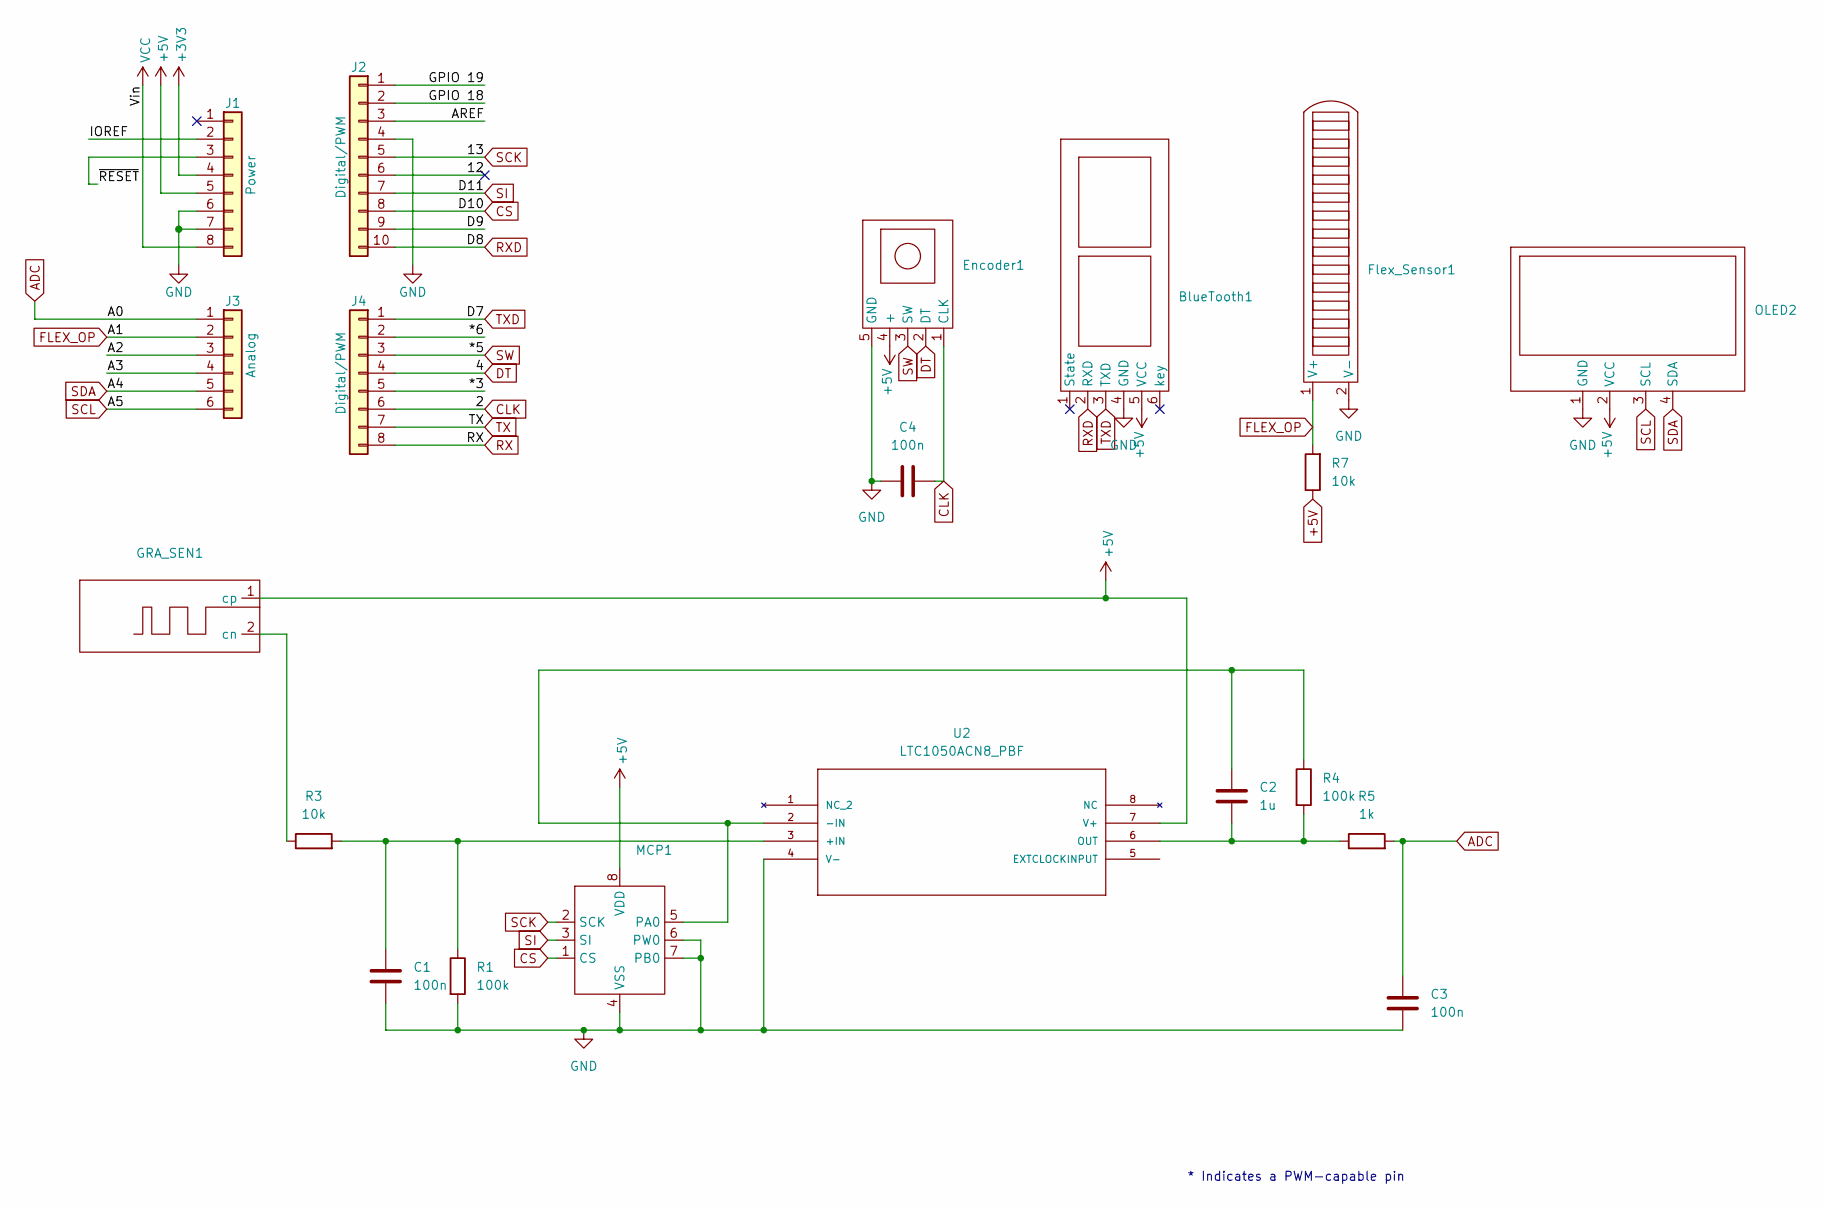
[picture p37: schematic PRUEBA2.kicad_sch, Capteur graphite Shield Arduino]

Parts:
BlueTooth1: Bluetooth
C1, C3, C4: 100n; C_Disc_D4.7mm_W2.5mm_P5.00mm
C2: 1u; C_Rect_L7.0mm_W2.5mm_P5.00mm
Encoder1: Encoder_rotation
Flex_Sensor1: Sensor
GRA_SEN1: Sensor
J1: Power; PinSocket_1x08_P2.54mm_Vertical
J2: Digital/PWM; PinSocket_1x10_P2.54mm_Vertical
J3: Analog; PinSocket_1x06_P2.54mm_Vertical
J4: Digital/PWM; PinSocket_1x08_P2.54mm_Vertical
MCP1: DIP-8_296_ELL
OLED2: OLED
R1, R4: 100k; R_Axial_DIN0207_L6.3mm_D2.5mm_P15.24mm_Horizontal
R3, R7: 10k; R_Axial_DIN0207_L6.3mm_D2.5mm_P15.24mm_Horizontal
R5: 1k; R_Axial_DIN0207_L6.3mm_D2.5mm_P15.24mm_Horizontal
U2: LTC1050ACN8_PBF; DIP-8_296_ELL

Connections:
+3V3: J1.4
+5V: BlueTooth1.5 (VCC), Encoder1.4 (+), GRA_SEN1.1 (cp), J1.5, MCP1.8 (VDD), OLED2.2 (VCC), R7.1, U2.7 (V+)
/12: J2.6
/*3: J4.5
/*6: J4.2
/A2: J3.3
/A3: J3.4
/AREF: J2.3
/D9: J2.9
/GPIO 18: J2.2
/GPIO 19: J2.1
/IOREF: J1.2
/~RESET: J1.3
ADC: C3.1, J3.1, R5.2
CLK: C4.1, Encoder1.1 (CLK), J4.6
CS: J2.8, MCP1.1 (CS)
DT: Encoder1.2 (DT), J4.4
FLEX_OP: Flex_Sensor1.1 (V+), J3.2, R7.2
GND: BlueTooth1.4 (GND), C1.2, C3.2, C4.2, Encoder1.5 (GND), Flex_Sensor1.2 (V-), J1.6, J1.7, J2.4, MCP1.4 (VSS), MCP1.6 (PW0), MCP1.7 (PB0), OLED2.1 (GND), R1.2, U2.4 (V-)
unnamed: GRA_SEN1.2 (cn), R3.1
unnamed: C2.1, MCP1.5 (PA0), R4.1, U2.2 (-IN)
unnamed: C1.1, R1.1, R3.2, U2.3 (+IN)
unnamed: C2.2, R4.2, R5.1, U2.6 (OUT)
RX: J4.8
RXD: BlueTooth1.2 (RXD), J2.10
SCK: J2.5, MCP1.2 (SCK)
SCL: J3.6, OLED2.3 (SCL)
SDA: J3.5, OLED2.4 (SDA)
SI: J2.7, MCP1.3 (SI)
SW: Encoder1.3 (SW), J4.3
TX: J4.7
TXD: BlueTooth1.3 (TXD), J4.1
VCC: J1.8

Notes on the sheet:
* Indicates a PWM-capable pin

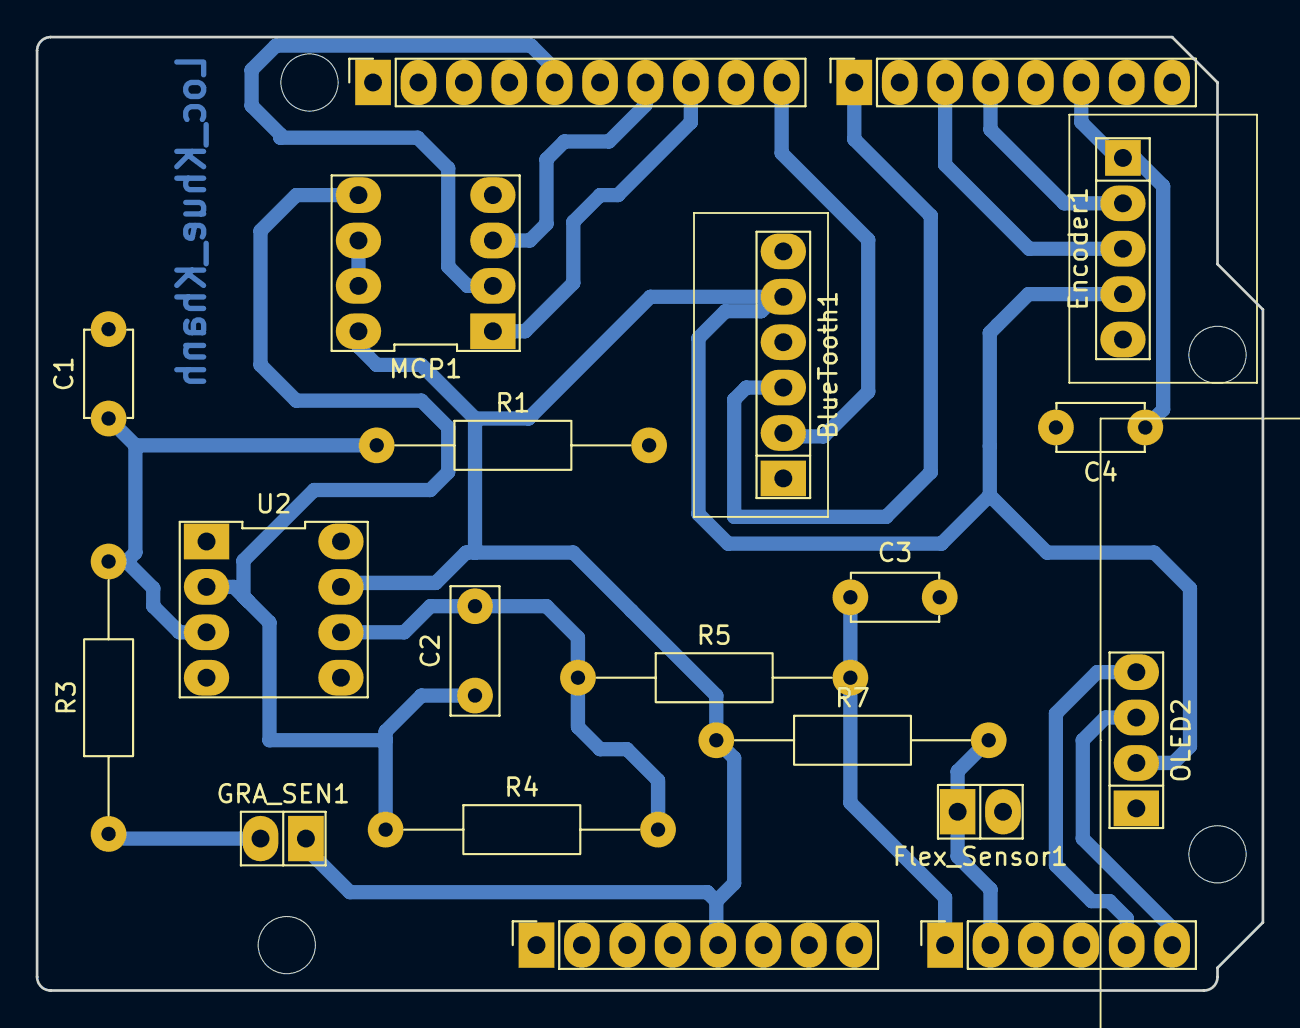
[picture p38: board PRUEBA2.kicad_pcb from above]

Board: 2 copper layers, 68.6 x 53.3 mm, 24 parts (0 on the bottom side), 18 nets.

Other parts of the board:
MH1, MH2, MH3, MH4: MountingHole_3.2mm

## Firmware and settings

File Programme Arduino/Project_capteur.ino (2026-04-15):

#include <Wire.h>

#include <Adafruit_SSD1306.h>
#include <Adafruit_GFX.h>

//----------------- BlueTooth--------------------
#include <SoftwareSerial.h>
#define pinBT_TXD 8
#define pinBT_RXD 7
SoftwareSerial BTSerial(pinBT_RXD, pinBT_TXD); //
bool bluetoothMeasureGraphite = false;
bool bluetoothMeasureFlex = false;
unsigned long lastSampleMs = 0;
// ---------------- Encoder pins ----------------
#define encoder0PinA 2   // Encoder CLK (interrupt pin)
#define encoder0PinB 4  // Encoder DT
#define Switch 5       // Encoder push button

volatile int encoder0Pos = 0; // Updated inside ISR

// ---------------- OLED config ----------------
#define OLED_W 128
#define OLED_H 64
#define OLED_RST -1
#define OLED_ADDR 0x3C
Adafruit_SSD1306 ecranOLED(OLED_W, OLED_H, &Wire, OLED_RST);

// ---------------- Digital potentiometer / R2 model ----------------
// Note: This code only computes resistanceWB from the wiper position.
// It does not send commands to an MCP42100 (SPI part not included here).
const int  maxPositions = 256;
const long rAB = 92500;
const byte rWiper = 125;

long resistanceWB = 0;   // Estimated resistance W->B (ohms)
int  r2WiperPos   = 0;   // 0..255

// ---------------- Sensors ----------------
#define pinFlexSensor A2
const float VCC   = 5.0;
const float R_DIV = 1000;   // Divider resistor for flex sensor

#define pinGraphiteSensor A0
const float R1 = 100000;
const float R3 = 100000;
const float R5 = 10000;

// ---------------- Menu state ----------------
// Only 3 screens as requested.
enum MenuLevel { MAIN_MENU, MESURE_MENU, ADJUST_R2 };
MenuLevel menuLevel = MAIN_MENU;

int menuIndex = 0;
int lastMenuIndex = -1;
MenuLevel lastMenuLevel = MAIN_MENU;

// Menu entries
const char* mainItems[]   = { "Resistance R2", "Mesure" };
const int mainCount = sizeof(mainItems) / sizeof(mainItems[0]);

const char* mesureItems[] = { "Flex sensor", "Capteur graphite", "< Back" };
const int mesureCount = sizeof(mesureItems) / sizeof(mesureItems[0]);

// ---------------- Button debounce ----------------
bool lastBtn = HIGH;
unsigned long lastBtnMs = 0;
const unsigned long btnDebounceMs = 30;

// ---------------- UI rate limiting (encoder) ----------------
int lastPosUI = 0;
unsigned long lastEncMs = 0;
const unsigned long encStepMs = 10;

// ---------------- Measurement settings ----------------
// Measurements run only on Serial Monitor (OLED does not show measurement screen).
const int N_SAMPLES = 50;
const unsigned long samplePeriodMs = 50;

// ---------------- Prototypes ----------------
// Adding explicit prototypes avoids Arduino auto-prototype quirks.
void drawMenu(bool force);
void drawAdjustR2Screen();
void onSelect();
void handleEncoderUI();
void handleButton();
float Flex_Mesure();
float Graphite_Mesure();
void startMeasurementFlex();
void startMeasurementGraphite();
void updateResistanceFromWiper();
//----------------- Function bluetooth----------
void handleBluetoothCommands() {
  if (BTSerial.available() > 0) {
    char cmd = BTSerial.read();
    Serial.println(cmd);
    if (cmd == 'm') {
      bluetoothMeasureGraphite = true;
    } 
    if (cmd == 'f') {
      bluetoothMeasureFlex = true;
    } 
    else if (cmd == 's') {
      bluetoothMeasureGraphite = false;
      bluetoothMeasureFlex = false;
    }
  }
  //else  Serial.println("is not connected");
}

void sendGraphiteDataBluetooth() {
  if (!bluetoothMeasureGraphite) return;

  if (millis() - lastSampleMs >= 100) {
    lastSampleMs = millis();

    float r = Graphite_Mesure();

    if (!isnan(r)) {
      BTSerial.println(r, 3);
      Serial.println(r,3);

    } else {
      BTSerial.println(0);
    }
  }
}
void sendFlexDataBluetooth() {
  if (!bluetoothMeasureFlex) return;

  if (millis() - lastSampleMs >= 100) {
    lastSampleMs = millis();

    float r = Flex_Mesure();

    if (!isnan(r)) {
      BTSerial.println(r, 3);
      Serial.println(r,3);

    } else {
      BTSerial.println(0);
    }
  }
}
// ---------------- Encoder ISR ----------------
// Very short interrupt routine: updates encoder0Pos.
void doEncoder() {
  if (digitalRead(encoder0PinA) == HIGH) {
    if (digitalRead(encoder0PinB) == HIGH) encoder0Pos++;
    else encoder0Pos--;
  }
}

// Compute the estimated resistance from wiper position.
// Also clamps against 0 to avoid divide-by-zero in graphite math.
void updateResistanceFromWiper() {
  resistanceWB = ((rAB * (long)r2WiperPos) / maxPositions) + rWiper;
  if (resistanceWB < 1) resistanceWB = 1;
}

// Read flex sensor resistance from a voltage divider.
float Flex_Mesure() {
  int adc = analogRead(pinFlexSensor);
  float v = (adc * VCC) / 1023.0f;

  // Avoid divide-by-zero if v is too close to 0 or VCC
  if (v <= 0.001f || v >= (VCC - 0.001f)) return NAN;

  float r = R_DIV * (v / (VCC - v));
  return r;
}

// Read graphite sensor resistance based on your formula.
// Protects against invalid ADC voltage and resistanceWB == 0.
float Graphite_Mesure() {
  int adc = analogRead(pinGraphiteSensor);
  float v_adc = adc * VCC / 1023.0f;

  if (v_adc <= 0.001f) return NAN;
  if (resistanceWB <= 0) return NAN;

  float gain = 1.0f + (R3 / (float)resistanceWB);
  float r = gain * R1 * (VCC / v_adc) - (R1 + R5);
  return r;
}

// Run a short measurement burst and print to Serial only.
void startMeasurementFlex() {
  Serial.println("BEGIN,FLEX");
  float sum = 0;
  for (int i = 0; i < N_SAMPLES; i++) {
    float v = Flex_Mesure();
    Serial.print("FLEX,");
    Serial.print(i);
    Serial.print(",");
    if (isnan(v)) Serial.println("nan");
    else {
      Serial.println(v, 3);
      sum = sum + v;
      delay(samplePeriodMs);
    }
  }
  float avg = sum/N_SAMPLES;
  Serial.println(avg);
  Serial.println("END");
}

// Run a short measurement burst and print to Serial only.
void startMeasurementGraphite() {
  Serial.println("BEGIN,GRAPHITE");
  float sum = 0;
  for (int i = 0; i < N_SAMPLES; i++) {
    float v = Graphite_Mesure();
    Serial.print("GRAPHITE,");
    Serial.print(i);
    Serial.print(",");
    if (isnan(v)) Serial.println("nan");
    else {
      Serial.println(v, 3);
      sum = sum + v;
      delay(samplePeriodMs);
    }
  }
  float avg = sum/N_SAMPLES;
  Serial.println(avg);
  Serial.println("END");
}

void setup() {
  Serial.begin(9600);
  BTSerial.begin(9600);
  // Encoder setup
  pinMode(encoder0PinA, INPUT_PULLUP);
  pinMode(encoder0PinB, INPUT_PULLUP);
  pinMode(Switch, INPUT_PULLUP);
  attachInterrupt(digitalPinToInterrupt(encoder0PinA), doEncoder, RISING);

  // I2C setup for OLED
  Wire.begin();
  Wire.setClock(100000);

  // OLED init (will stop here forever if failed)
  if (!ecranOLED.begin(SSD1306_SWITCHCAPVCC, OLED_ADDR)) {
    while (1) {}
  }

  ecranOLED.clearDisplay();
  ecranOLED.setTextSize(1);
  ecranOLED.setTextColor(SSD1306_WHITE);

  // Initialize R2 position and computed resistance
  r2WiperPos = constrain(r2WiperPos, 0, 255);
  encoder0Pos = r2WiperPos;
  updateResistanceFromWiper();

  // Draw initial menu
  drawMenu(true);
}

// Handle encoder rotation:
// - In ADJUST_R2: changes wiper position
// - In menus: changes highlighted item
void handleEncoderUI() {
  if (millis() - lastEncMs < encStepMs) return;
  lastEncMs = millis();

  int pos = encoder0Pos;
  if (pos == lastPosUI) return;

  int delta = (pos > lastPosUI) ? 1 : -1;
  lastPosUI = pos;

  if (menuLevel == ADJUST_R2) {
    r2WiperPos += delta;

    if (r2WiperPos < 0) r2WiperPos = 0;
    if (r2WiperPos > 255) r2WiperPos = 255;

    // Keep encoder position aligned with the wiper value
    encoder0Pos = r2WiperPos;
    updateResistanceFromWiper();
    return;
  }

  int count = (menuLevel == MAIN_MENU) ? mainCount : mesureCount;

  menuIndex += delta;
  if (menuIndex < 0) menuIndex = 0;
  if (menuIndex > count - 1) menuIndex = count - 1;
}

// Debounced button handling:
// calls onSelect() once per press.
void handleButton() {
  bool btn = digitalRead(Switch);

  if (btn != lastBtn) {
    lastBtnMs = millis();
    lastBtn = btn;
  }

  if (millis() - lastBtnMs < btnDebounceMs) return;

  static bool handledPress = false;
  if (btn == LOW && !handledPress) {
    handledPress = true;
    onSelect();
  }
  if (btn == HIGH) handledPress = false;
}

// Menu selection behavior:
// - MAIN_MENU: enter ADJUST_R2 or MESURE_MENU
// - MESURE_MENU: run measurement on Serial OR go back
// - ADJUST_R2: back to MAIN_MENU
void onSelect() {
  if (menuLevel == MAIN_MENU) {
    if (menuIndex == 0) {
      menuLevel = ADJUST_R2;
      r2WiperPos = constrain(r2WiperPos, 0, 255);
      encoder0Pos = r2WiperPos;
      updateResistanceFromWiper();
    } else if (menuIndex == 1) {
      menuLevel = MESURE_MENU;
      menuIndex = 0;
    }
  } else if (menuLevel == MESURE_MENU) {
    if (menuIndex == 0) {
      startMeasurementFlex();
    } else if (menuIndex == 1) {
      startMeasurementGraphite();
    } else if (menuIndex == 2) {
      menuLevel = MAIN_MENU;
      menuIndex = 0;
    }
  } else if (menuLevel == ADJUST_R2) {
    menuLevel = MAIN_MENU;
    menuIndex = 0;
  }

  // Redraw menu after any selection
  drawMenu(true);
}

// OLED screen for R2 adjustment only.
void drawAdjustR2Screen() {
  ecranOLED.clearDisplay();
  ecranOLED.setCursor(0, 0);
  ecranOLED.println("R2");
  ecranOLED.println();
  ecranOLED.print("Wiper: ");
  ecranOLED.println(r2WiperPos);
  ecranOLED.print("R: ");
  ecranOLED.print(resistanceWB);
  ecranOLED.println(" ohms");
  ecranOLED.println();
  ecranOLED.println("Press to back");
  ecranOLED.display();
}

// OLED rendering:
// - ADJUST_R2 shows R2 screen
// - MAIN_MENU and MESURE_MENU show a simple list with ">" cursor
void drawMenu(bool force) {
  if (menuLevel == ADJUST_R2) {
    drawAdjustR2Screen();
    return;
  }

  // Skip redraw if nothing changed
  if (!force && menuLevel == lastMenuLevel && menuIndex == lastMenuIndex) return;

  lastMenuLevel = menuLevel;
  lastMenuIndex = menuIndex;

  ecranOLED.clearDisplay();
  ecranOLED.setCursor(0, 0);

  const char** items;
  int count;

  if (menuLevel == MAIN_MENU) {
    ecranOLED.println("MENU");
    items = mainItems;
    count = mainCount;
  } else {
    ecranOLED.println("MESURE");
    items = mesureItems;
    count = mesureCount;
  }

  for (int i = 0; i < count; i++) {
    ecranOLED.print(i == menuIndex ? "> " : "  ");
    ecranOLED.println(items[i]);
  }

  ecranOLED.display();
}

void loop() {
  handleEncoderUI();
  handleButton();
  drawMenu(false);

  handleBluetoothCommands();
  sendGraphiteDataBluetooth();
  sendFlexDataBluetooth();
  delay(100);
}

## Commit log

2026-02-24 Finish PCB files
    [PRUEBA2.kicad_pcb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]
2026-02-25 new update PCB
    [PRUEBA2.kicad_pcb]
2026-03-06 programme arduino
2026-03-06 update measure flex/graphtie sensor
    [Project_capteur.ino]
2026-03-22 Variation des meseures de capteurs
2026-03-22 Variation des mesures de capteurs
2026-03-25 Update README
    Added a section for project conception and listed required materials.
2026-04-08 Add LTSpice files
    [FLEX_SENSOR 115MM.SLDPRT, FS-L-0095-103-ST - Assembly.stp, FS-L-0095-103-ST - Base.stp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]
2026-04-08 Add LTSpice (for real)
    [FLEX_SENSOR 115MM.SLDPRT, FS-L-0095-103-ST - Assembly.stp, FS-L-0095-103-ST - Base.stp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]
2026-04-15 MIT and Code Arduino
2026-04-16 updates banc de test
2026-04-16 banc de test
2026-04-29 New udpdate banc de test
    [Banc de test.xlsx]
2026-05-30 Replace shield assembly image with system image
    Updated images in README and added new system image.
2026-05-30 Edit until Connection diagram and KiCad
    Need to continue writing the section about KiCad
2026-05-31 Fix links in README for KiCad and Arduino code
